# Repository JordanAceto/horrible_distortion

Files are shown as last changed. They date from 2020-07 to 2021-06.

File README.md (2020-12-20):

## stm32 based bitcrusher pedal

bit crusher pedal 

## Repository organization
- Schematics, BOM, kicad files, and gerbers are in the [hardware](https://github.com/JordanAceto/bit_crusher_pedal/tree/master/hardware) directory.
- Source files and instructions on how to flash the firmware are in the [firmware](https://github.com/JordanAceto/bit_crusher_pedal/tree/master/firmware) directory.
- The [reference_docs](https://github.com/JordanAceto/bit_crusher_pedal/tree/master/reference_docs) directory contains various datasheets for the components used by the system.
- There is a [user manual](https://github.com/JordanAceto/bit_crusher_pedal/tree/master/user_manual.pdf) in the root directory.

---

## License:
-  hardware: CC by 4.0
-  software: MIT license
-  by: Jordan Aceto

---

## Status of the project:

revision | schematic | pcb layout | firmware | built and tested |
---------|-----------|------------|----------|------------------|
1.1      | &#9745;   | &#9745;    | &#9745;  | &#9745;          |

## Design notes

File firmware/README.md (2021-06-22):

# STM32F334K6 bitcrusher firmware

## Brief overview of the algorithm:

ADC1 reads the control signals for bit-depth and sample rate automatically at a sample rate set by timer 3.
The control parameters are saved in a global signal via the DMA controller.

The audio signal is read by ADC2, triggered by timer 6, at a variable sample rate set by the sample-rate control signal.

The digitized audio signal is then processed by the bit crusher algorithm and output via DAC1.

A simple bicolor LED indicator is attached to two GPIO pins and acts as a basic signal strength and clipping indicator.

---

## Prerequisites for building and flashing the project:
- [arm-none-eabi toolchain](https://developer.arm.com/tools-and-software/open-source-software/developer-tools/gnu-toolchain/gnu-rm/downloads)
- [GNU make](https://www.gnu.org/software/make/)
- [st-link utility](https://www.st.com/en/development-tools/stsw-link004.html)
- A physical st-link device. I use an old [Nucleo board](https://www.st.com/en/evaluation-tools/stm32-nucleo-boards.html).
- If you have a different preferred method of flashing STM32 chips (openocd, etc) then feel free to go wild.

### To build the project:
- `$ make`

### To flash an STM32f334 chip connected to an st-link programmer via the SWD header:
- `$ make write`

---

## Firmware directory organization:
- `third_party` contains the STM32 supplied CMSIS files, assembly startup routine, and linker script.
- `BSP` is a very basic "Board Support Package", this module initializes and modifies the various stm32 peripherals used by the system.
- `lib` contains user library files.
- `src` contains the main application files.
- `bin` is the destination for output files generated by the build process.

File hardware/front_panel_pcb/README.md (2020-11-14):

# front panel:

## The front panel is simply a cheap and cheerful pcb panel, as an alternative to dymo labels or silkscreening 

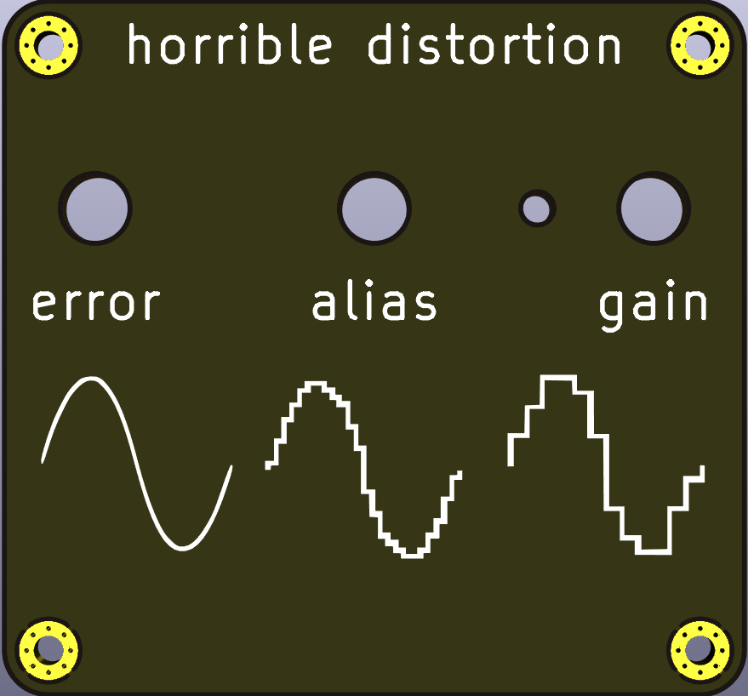
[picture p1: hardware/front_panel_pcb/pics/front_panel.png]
front panel


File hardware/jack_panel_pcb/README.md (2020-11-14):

# jack panel:

## The jack panel is simply a cheap and cheerful pcb panel, as an alternative to dymo labels or silkscreening 

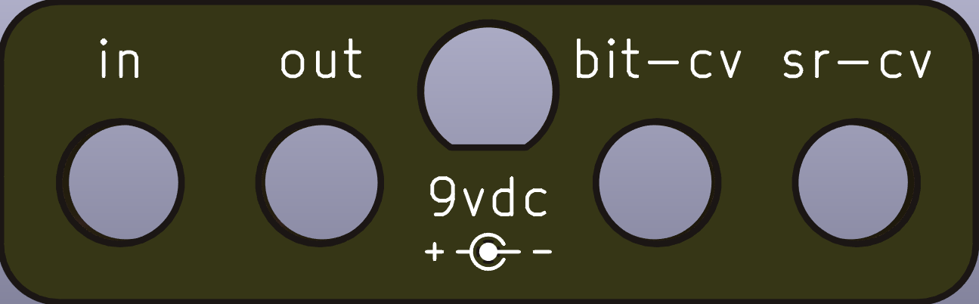
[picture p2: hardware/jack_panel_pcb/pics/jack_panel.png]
jack panel


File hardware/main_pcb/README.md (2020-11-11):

# main pcb:

<br /><br />

## The main pcb contains all the circuitry for the effect, excluding the 1/4" jacks, 9vdc power entry jack, and true-bypass footswitch. These off-board components are connected to the main pcb with soldered flying wires. 

<br /><br />

---

## Description of the audio circuit:

The audio signal is immediately buffered by a FET source-follower which provides a high impedance input as expected by guitars and other musical instruments.

The signal is then compressed by 1/2 of an NE570 compandor chip configured as a compressor. This compression squishes the audio signal into a reduced range so that both quiet and loud signals take up enough ADC resolution for the algorithm to work with.

The compressed audio signal is then sent to a variable gain amplifier where the user can adjust the magnitude of the signal entering the ADC to taste. This amplifier also acts as a clipping amplifier to protect the ADC from signals outside of its voltage range. A bi-color LED acts as a signal strength and clipping indicator as an aid to the user in setting a healthy signal level.

Now the signal is read in to the microcontroller by an onboard ADC and processed internally.

The processed digitized signal is then converted back to an analog signal by the microcontrollers onboard DAC.

The output of the DAC is fed into an opamp low pass filter to attenuate very high frequencies outside of the audio band.

The filtered processed signal is finally sent to the other half of the NE570 configured as an expandor this time. This restores the dynamic range of the original audio signal.

<br /><br />

---

## Description of the control circuit:

Control voltage signals for bit-depth and sample-rate are generated by opamps. The contribution of onboard rotary potentiometers and optional external control voltage signals are summed and inverted.

The opamp control voltage generators also act as protection for the ADC. Control voltages outside of the safe range for the ADC will be harmlessly clipped by the opamps.

These control voltage signals are then read in to the microcontroller by onboard ADCs and used to process the audio signals.

The external CV input ports can accept either voltage signals in the range of 0 volts to +5 volts, or they can accept an expression pedal connected to a TRS jack.

Because different brands of expression pedals use different potentiometer values, trim-pots are included to calibrate the device for various expression pedals.

<br /><br />

---

## Errata:

A port for an optional on/off LED indicator is included on the main pcb. If desired attach a panel mounted LED to this port through a spare pole of a bypass switch.

An SWD header is used to program and debug the STM32 microcontroller.

This project is intended as a "guitar pedal" type effects box which fits in a Hammond 'BB' style enclosure. The main pcb is affixed to the enclosure with the pcb mounted potentiometers. Flying wires are then routed to the chassis mounted 1/4" jacks, 9vdc power input jack, and true-bypass footswitch.

There are optional mounting holes if a different mechanical setup is desired.

<br /><br />

---

## Top and bottom render of the main pcb:

<br /><br />
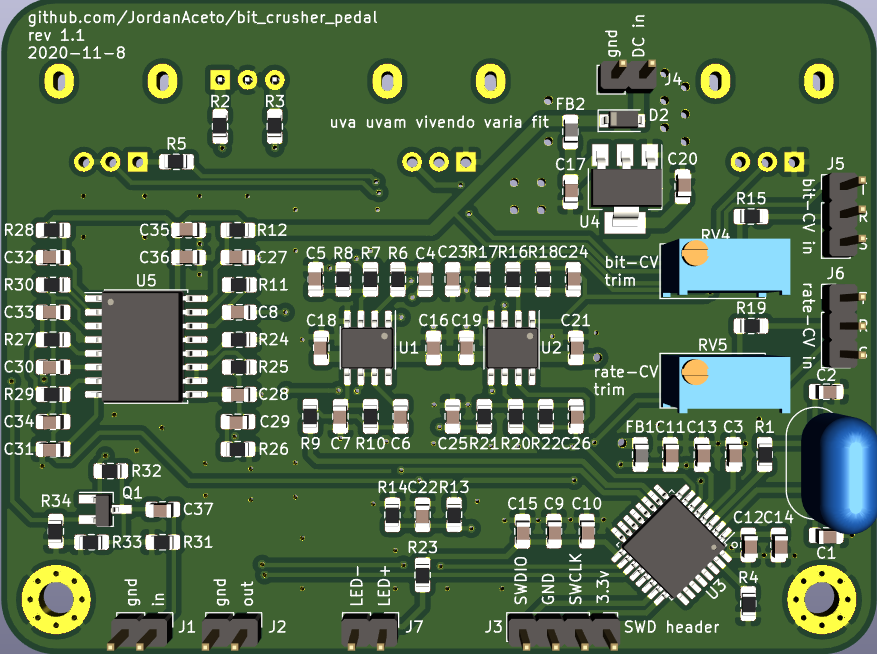
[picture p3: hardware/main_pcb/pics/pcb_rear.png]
main pcb


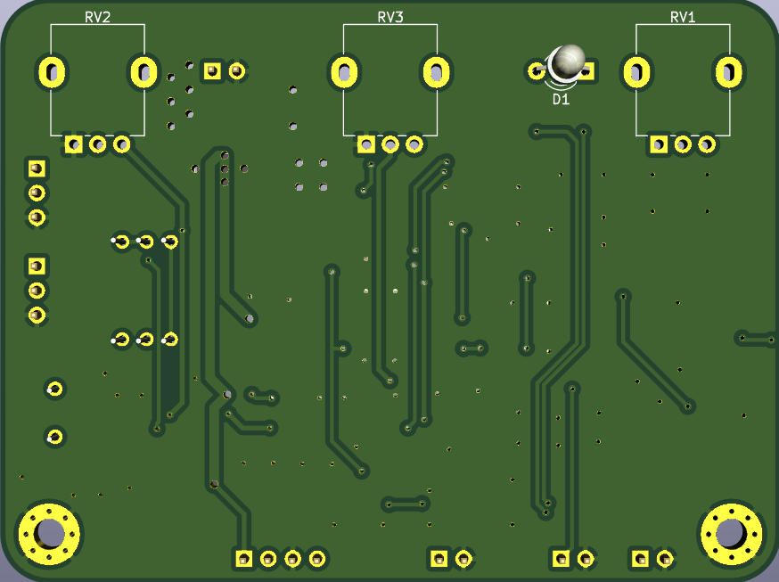
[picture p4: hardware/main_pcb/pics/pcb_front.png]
main pcb


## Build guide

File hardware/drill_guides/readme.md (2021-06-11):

## Printable drill guides





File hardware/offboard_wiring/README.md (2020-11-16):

# Offboard wiring

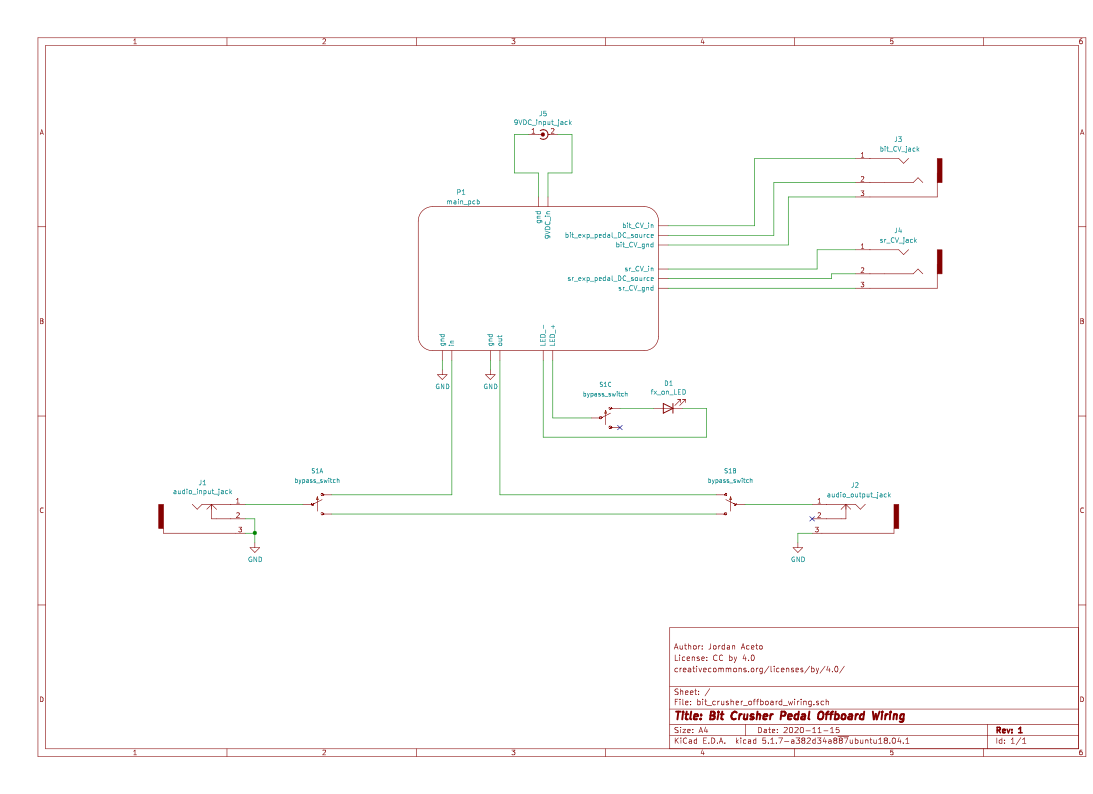
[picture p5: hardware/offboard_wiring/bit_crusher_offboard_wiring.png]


This directory simply contains a wiring diagram for the offboard components that
are wired to the main pcb with flying wires.

These components are:
- signal input and signal output jacks
- 9vdc power input jack
- bypass switch
- fx on/off indicator LED
- bit-depth and sample-rate CV input/expression pedal jacks

The builder is free to chose jacks, switches, and LEDs that work well for their
chosen enclosure.

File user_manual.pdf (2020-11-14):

# horrible distortion

- bit-crusher/sample-rate-reducer effects pedal -

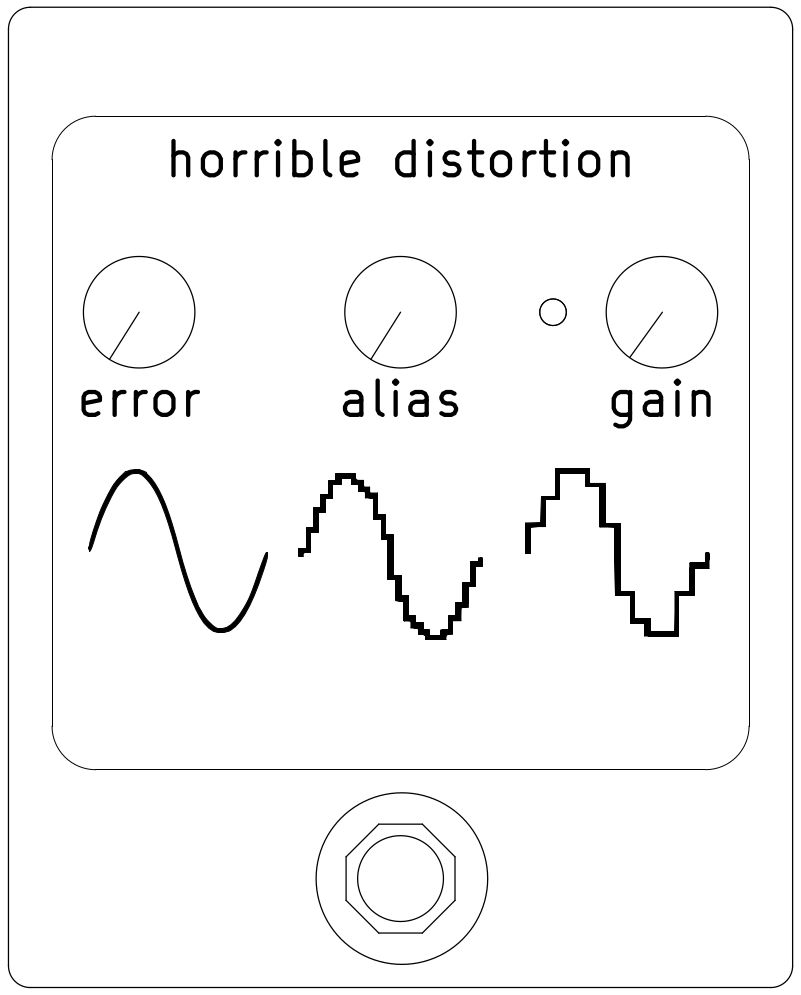
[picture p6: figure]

More docs and open source files at: github.com/JordanAceto/bit_crusher_pedal

Page | 1 | bit-crusher user manual

### Overview:

The horrible distortion pedal creates digital distortion and aliasing effects. Variable bit-depth and sample-rate parameters cause quantization noise, distortion, and harsh alias frequencies. How gauche.

### Front panel controls

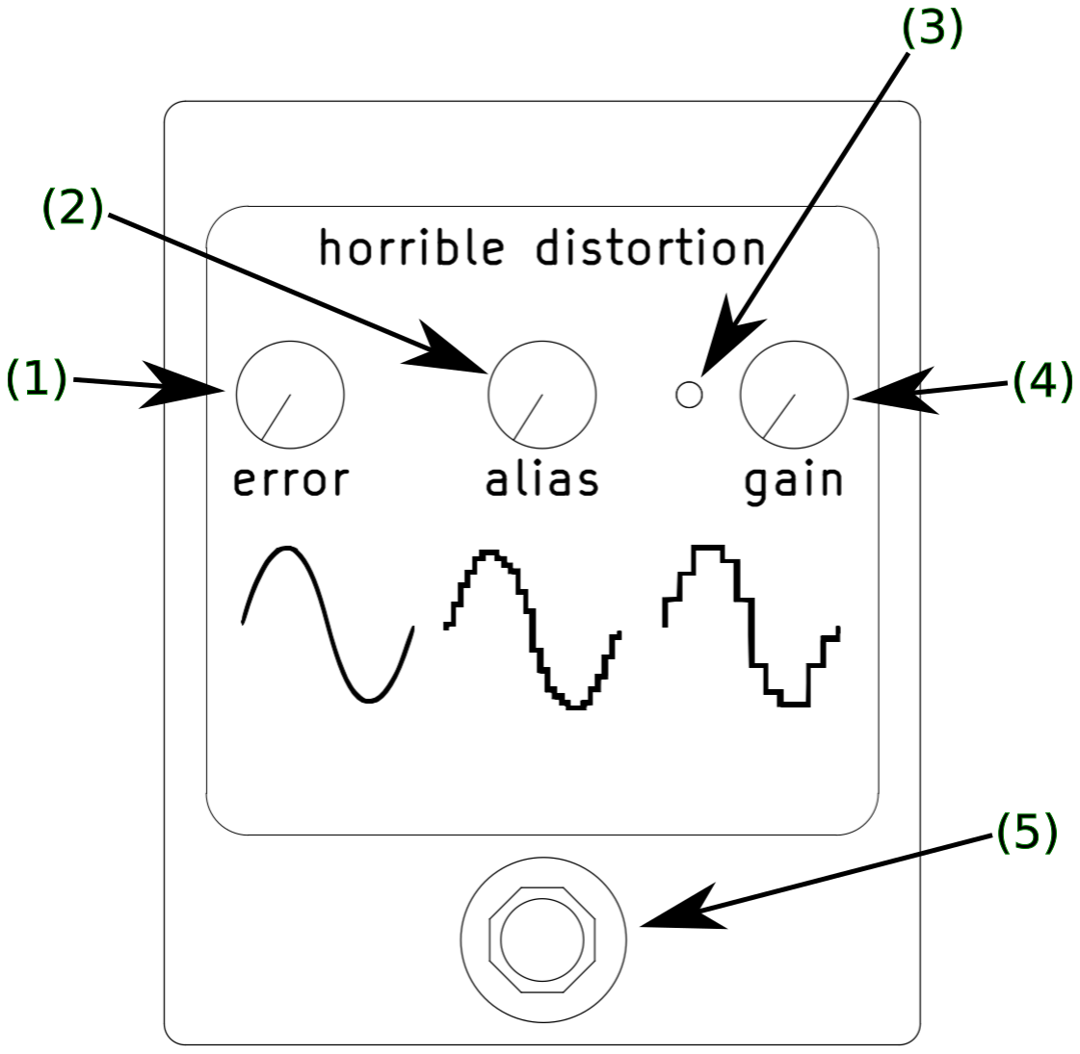
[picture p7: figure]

1) Error control which sets the bit-depth. As the control is advanced clockwise, the bit-depth resolution is decreased and harsh noise and distortion are introduced.
2) Alias control which reduces the sample-rate. Advancing this control clockwise adds alias frequencies and causes the frequency of the input signal to become unintelligible.
3) The signal level indicator gives a visual indication of the signal strength. The LED will be green when the signal level is in the healthy range, orange when approaching clipping, and red when clipping.
4) Gain control which sets the signal level. Adjust this control so that the LED is green most of the time while playing and the output volume is at the desired level.
5) True-bypass stomp switch which turns the effect on and off.

Page | 2 | bit-crusher user manual

### IO Jacks

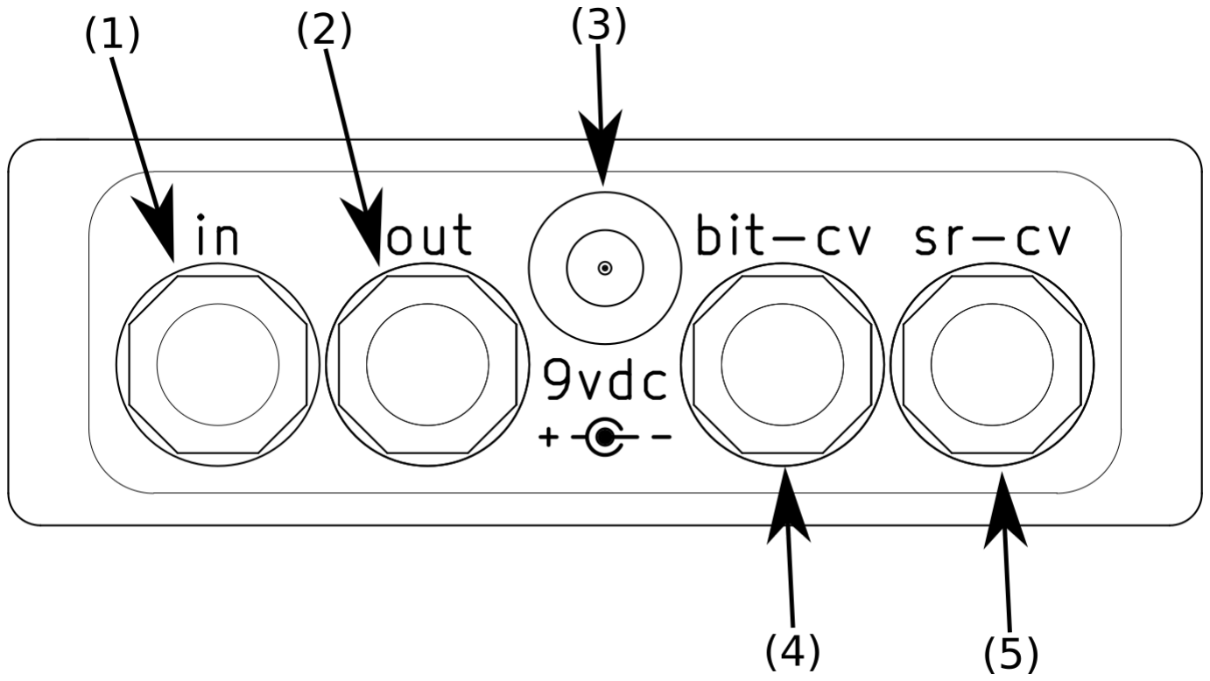
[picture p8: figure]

1) Audio signal input. Connect a guitar/synth/voice/drums/other instrument here.
2) Audio signal output jack. Connect this to an amplifier.
3) Plug a standard guitar pedal style 9-volt DC center-negative power supply here to energize the pedal.
4) The bit-cv jack accepts control voltages or expression pedals. Control signals injected into this jack modulate the bit-depth parameter in conjunction with the error rotary control.
5) Likewise, the sr-cv jack is the control voltage input for the sample-rate parameter. Control signals injected here modulate the sample-rate parameter in conjunction with the alias rotary control.

Page | 3 | bit-crusher user manual

### Control voltage input range

The bit-cv and sr-cv jacks expect control voltages between 0 volts and +5 volts. Control voltages outside this range will not harm the pedal, but will not modulate the parameters further.

### Expression pedal calibration

The bit-cv and sr-cv jacks can accept either control voltages or expression pedals. Expression pedals come in a variety of potentiometer values, and the pedal can be calibrated for the specific expression pedal you chose to use. You will need a multi meter and some basic electronics skills to carry out the calibration.

To calibrate the bit-cv expression pedal input:

- Connect the expression pedal you intend to use to the bit-cv jack.
- Remove the back cover with a screwdriver.
- Monitor across the outer terminals of the expression pedal potentiometer with a multimeter set to measure DC volts.
- Adjust the trimpot on the main circuit board labeled “bit-CV trim” until you read +5 volts across the expression pedal potentiometer.

Calibration of the sr-cv input is identical. Plug the expression pedal into the sr-cv jack and adjust the “rate-CV trim” trimpot.

If you do not have access to a multi meter, then the expression pedals can be calibrated by ear as well. Simply plug in an expression pedal and rock it through its range with various settings of the front panel controls and adjust the trim pots until the range of the expression pedal feels good.

The goal of the calibration is to make the sweep of the expression pedal feel right for your playing style and setup, so if it sounds good, it is good.

### Current Consumption

The pedal consumes approximately 50 mA from the 9 vdc power supply.

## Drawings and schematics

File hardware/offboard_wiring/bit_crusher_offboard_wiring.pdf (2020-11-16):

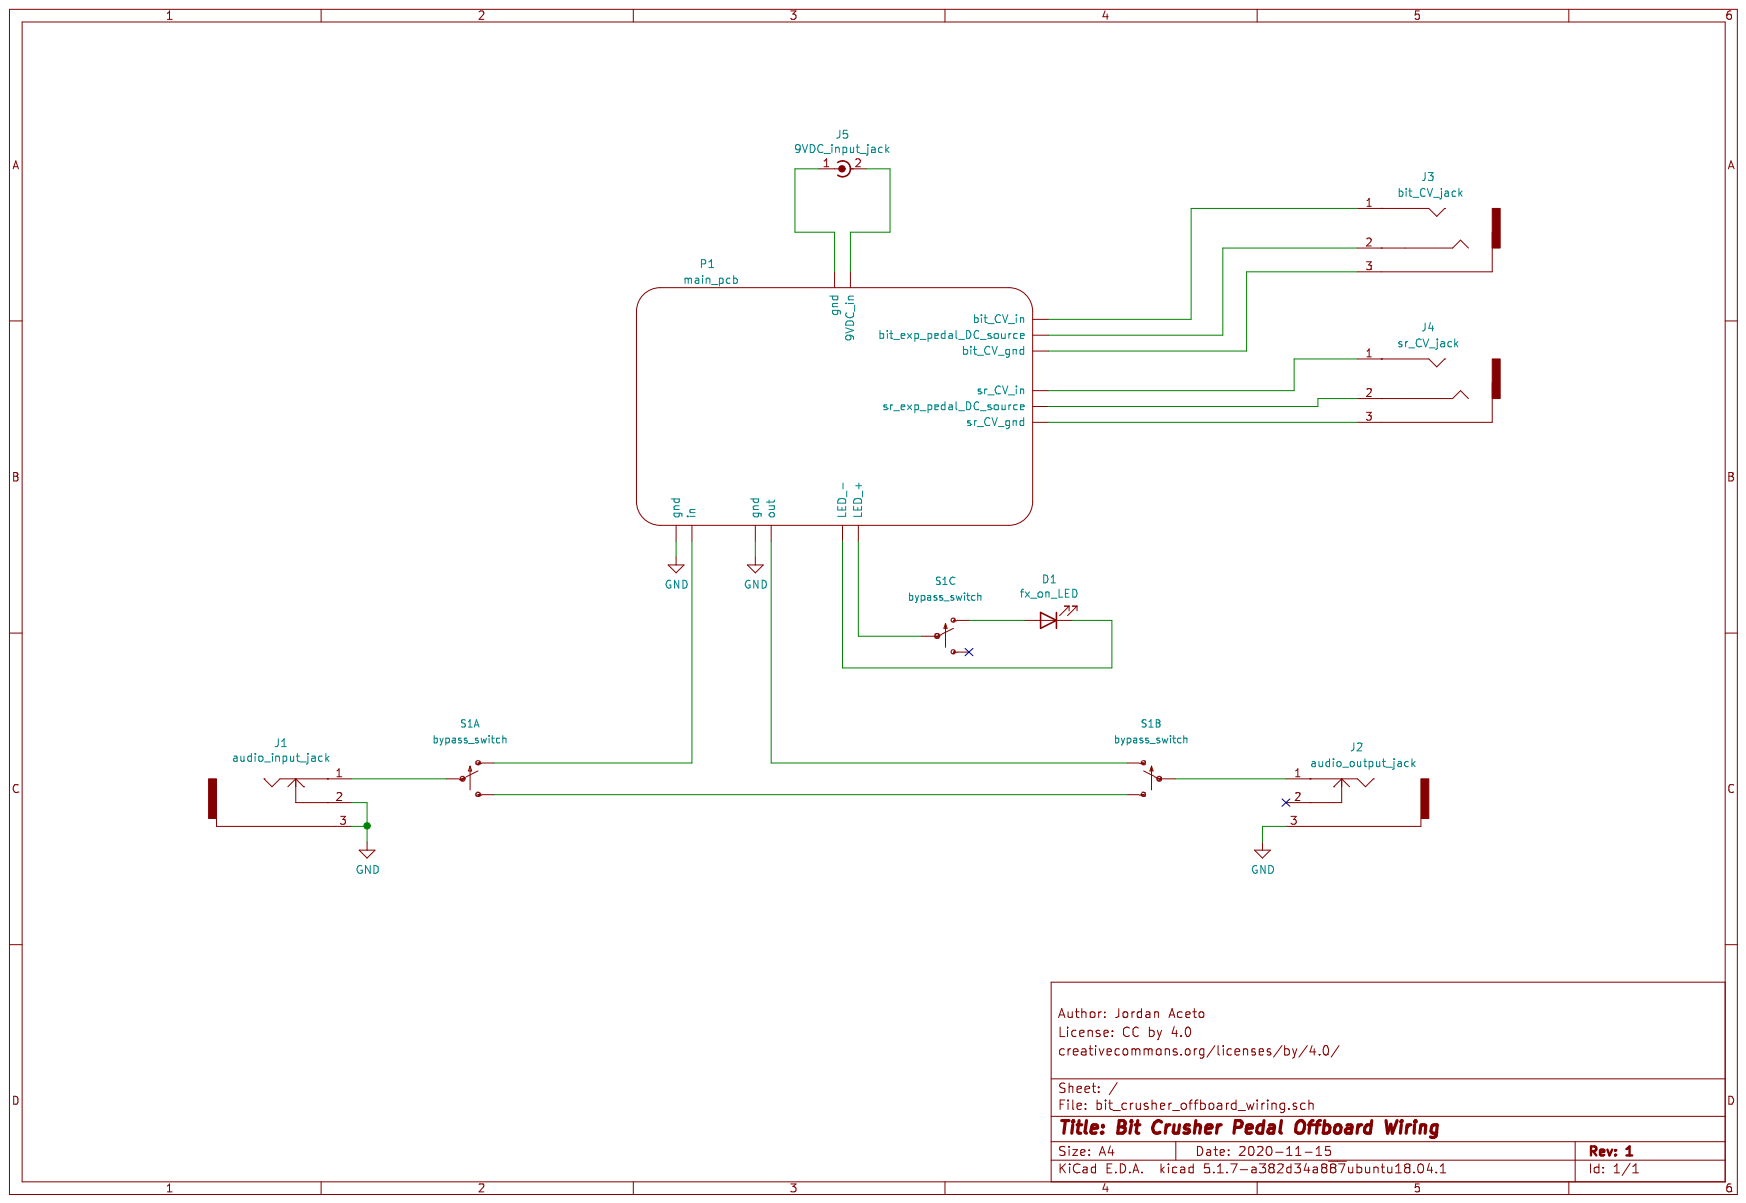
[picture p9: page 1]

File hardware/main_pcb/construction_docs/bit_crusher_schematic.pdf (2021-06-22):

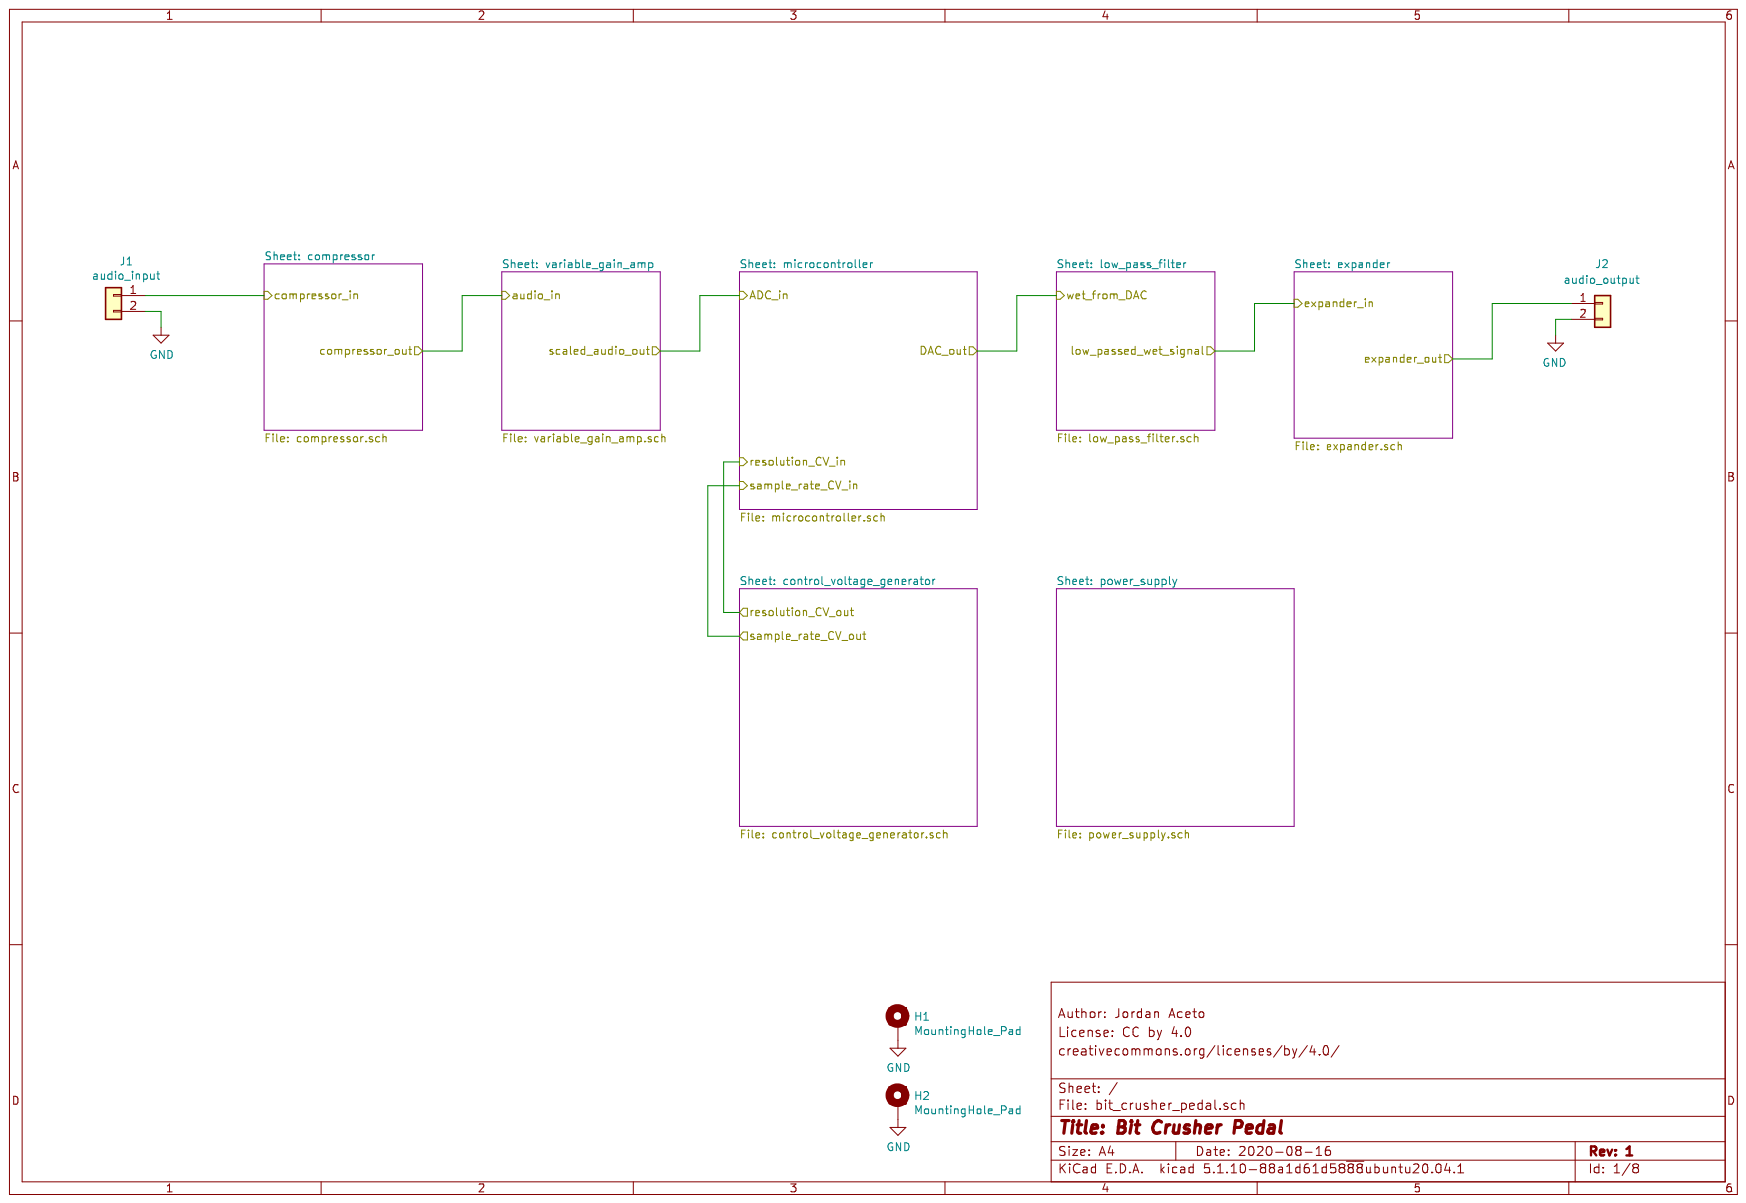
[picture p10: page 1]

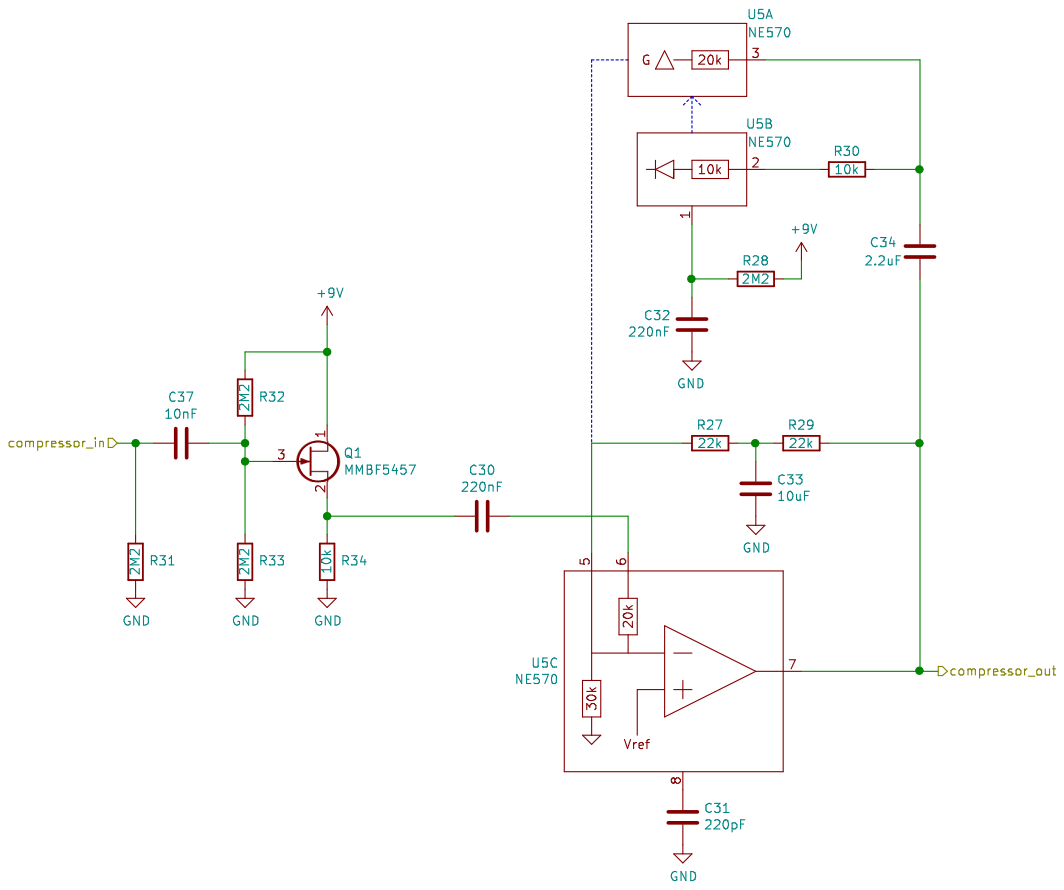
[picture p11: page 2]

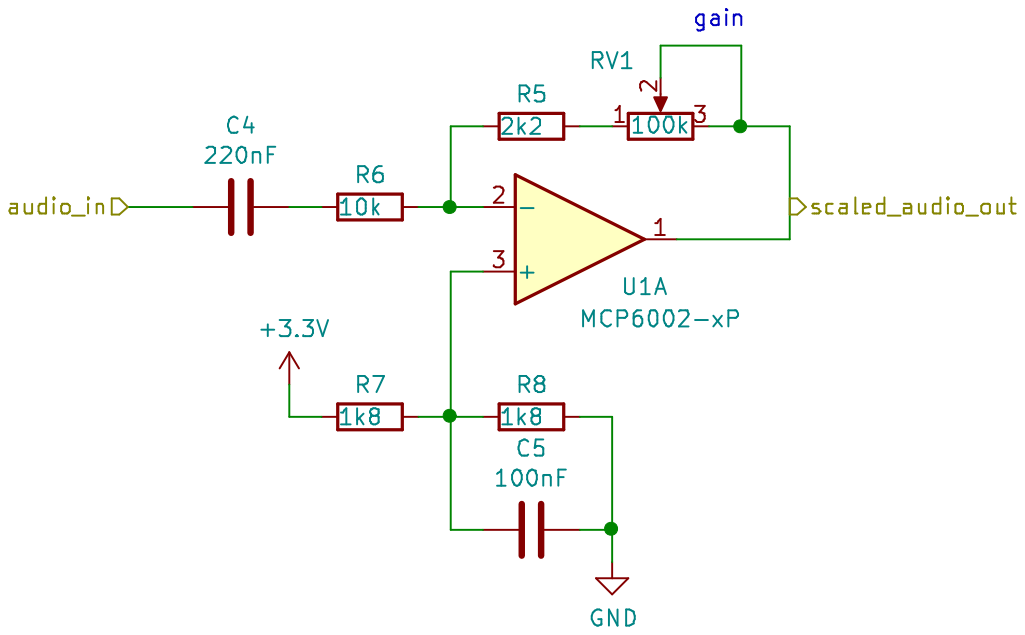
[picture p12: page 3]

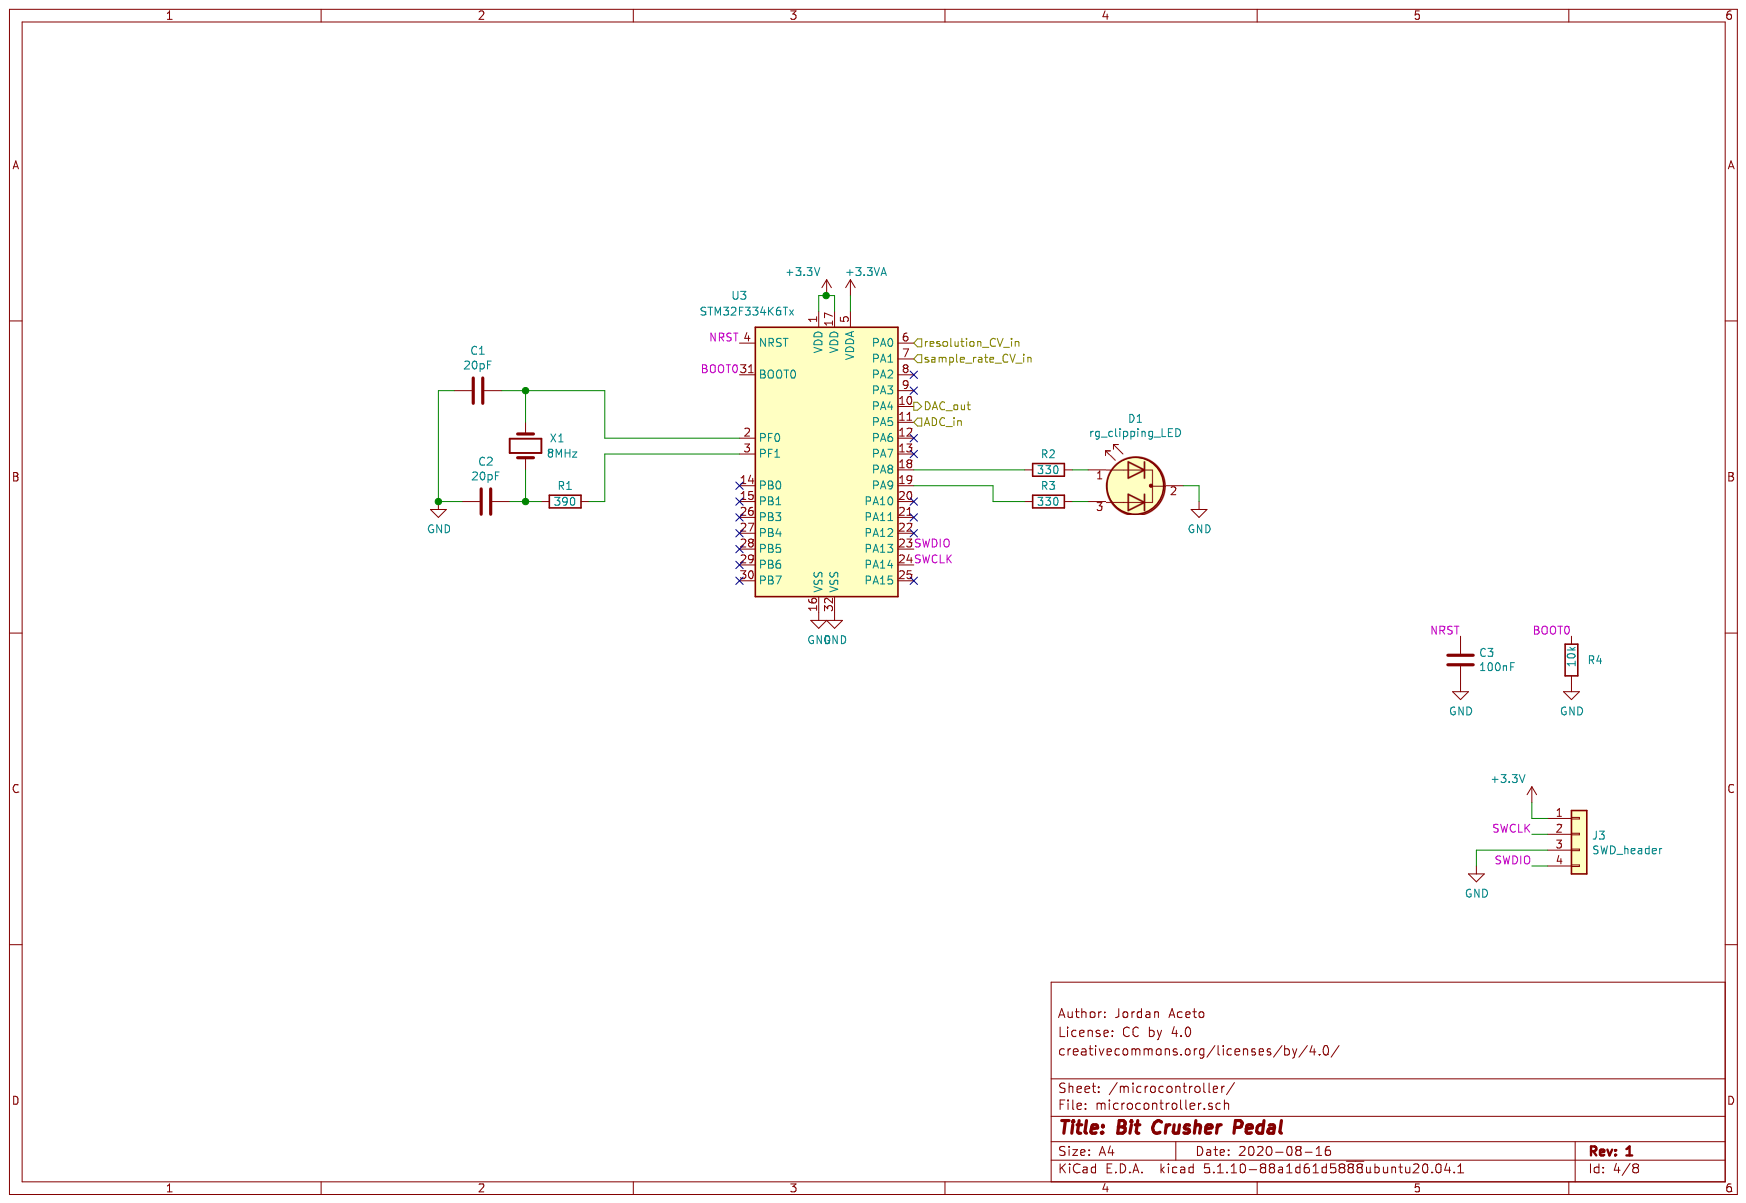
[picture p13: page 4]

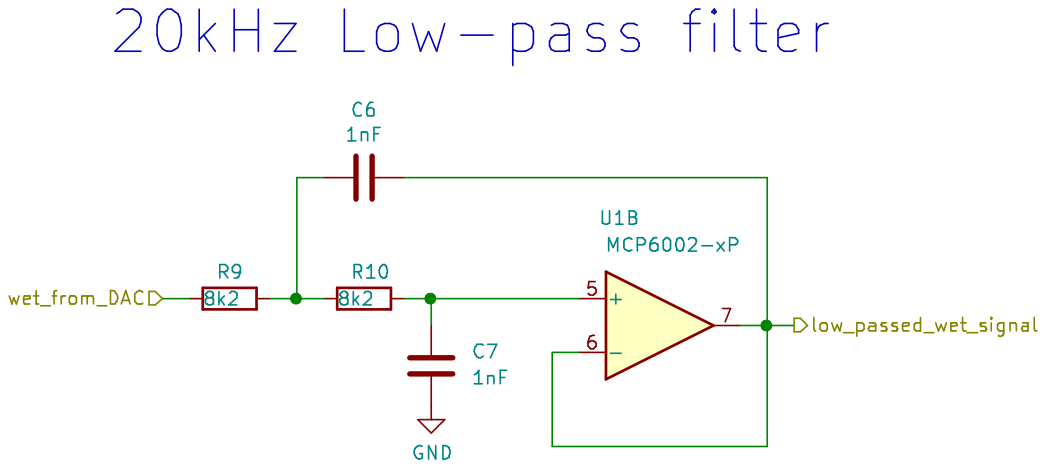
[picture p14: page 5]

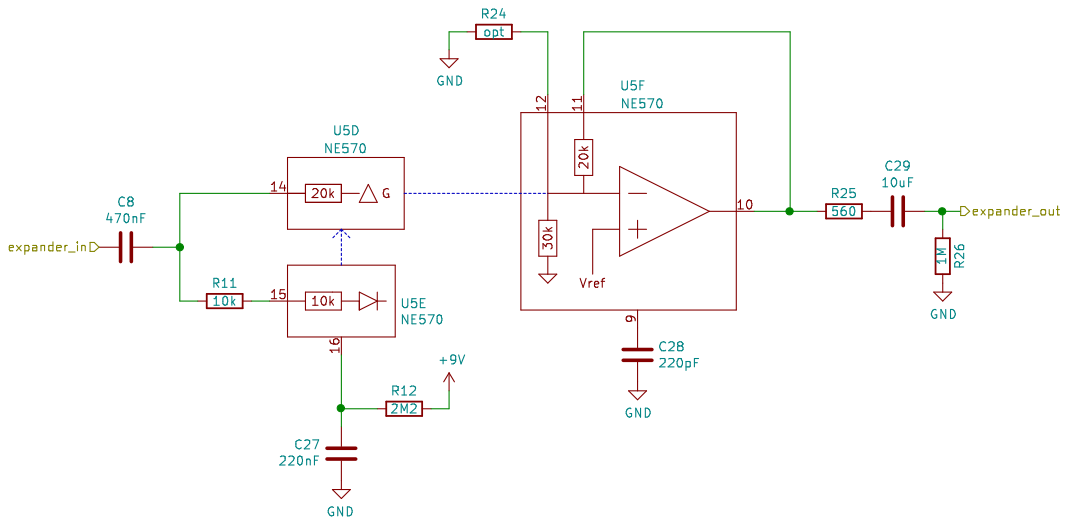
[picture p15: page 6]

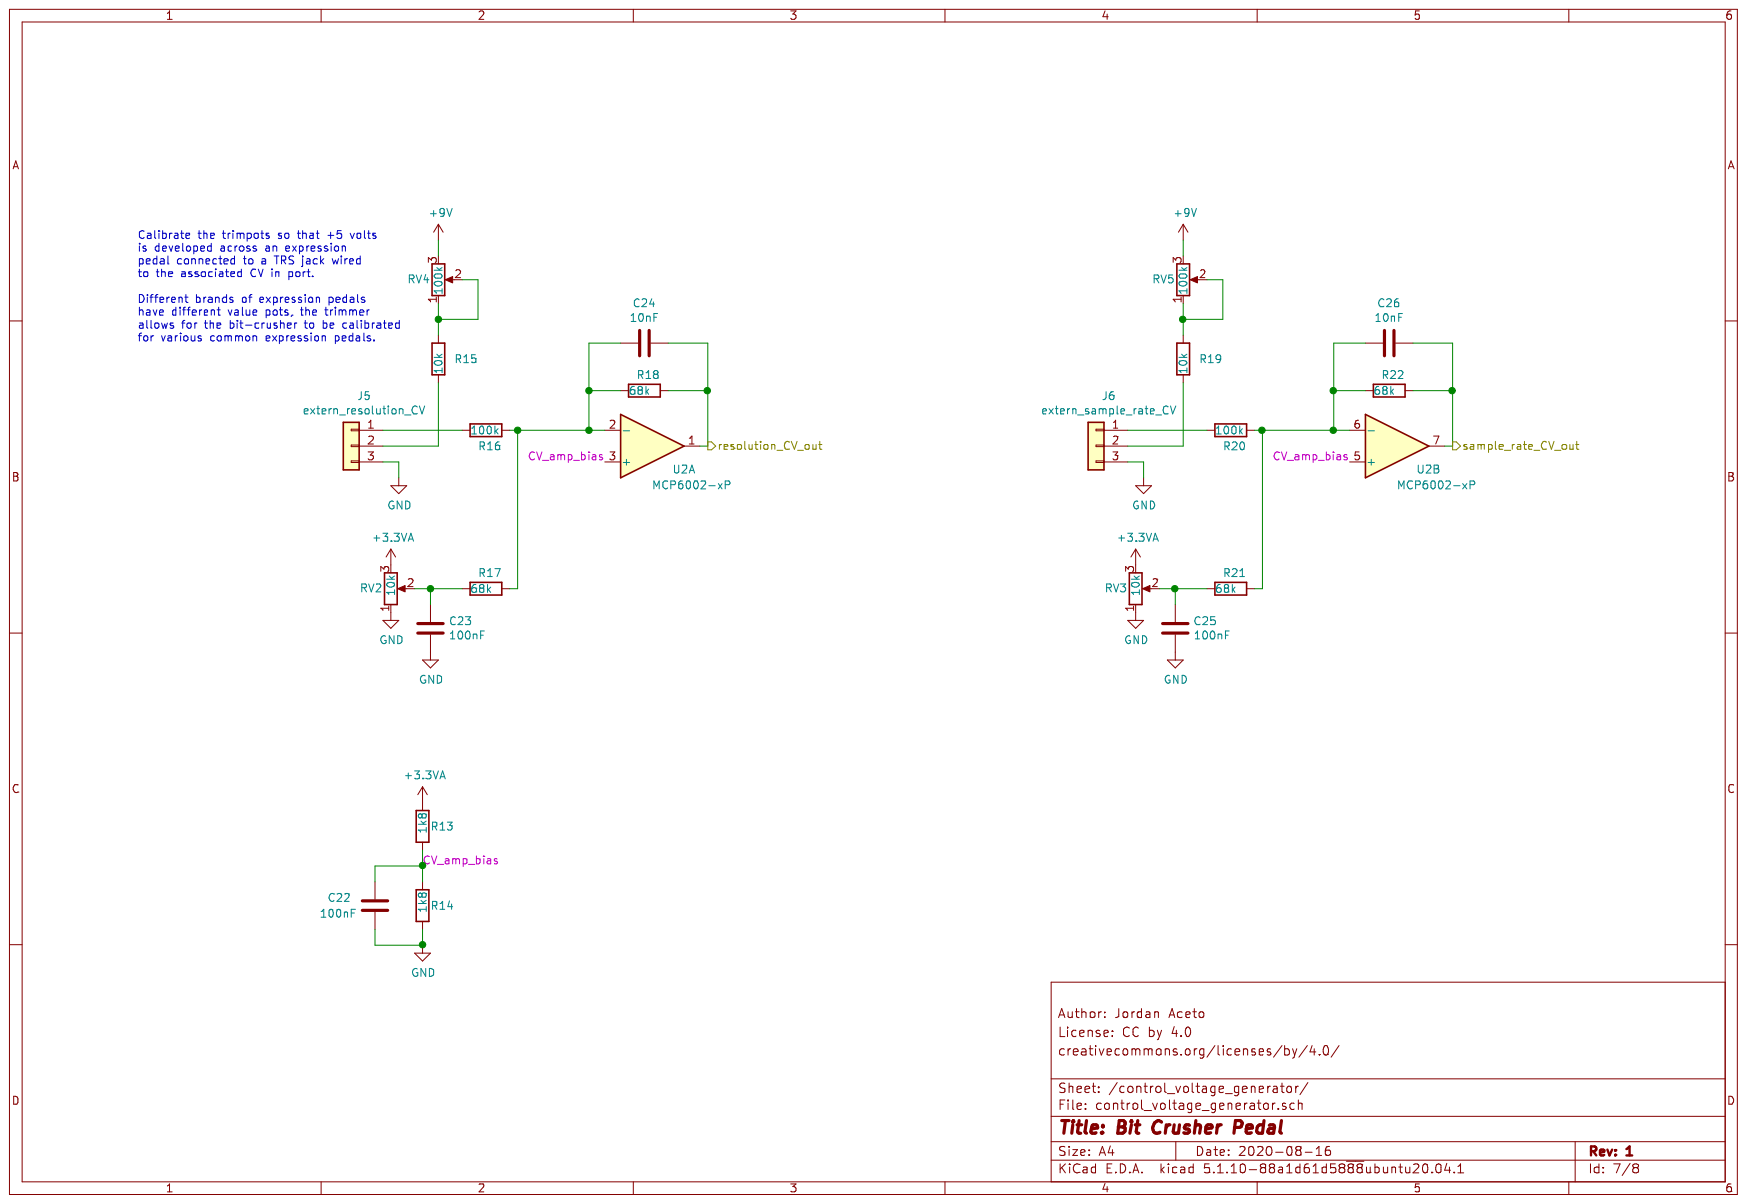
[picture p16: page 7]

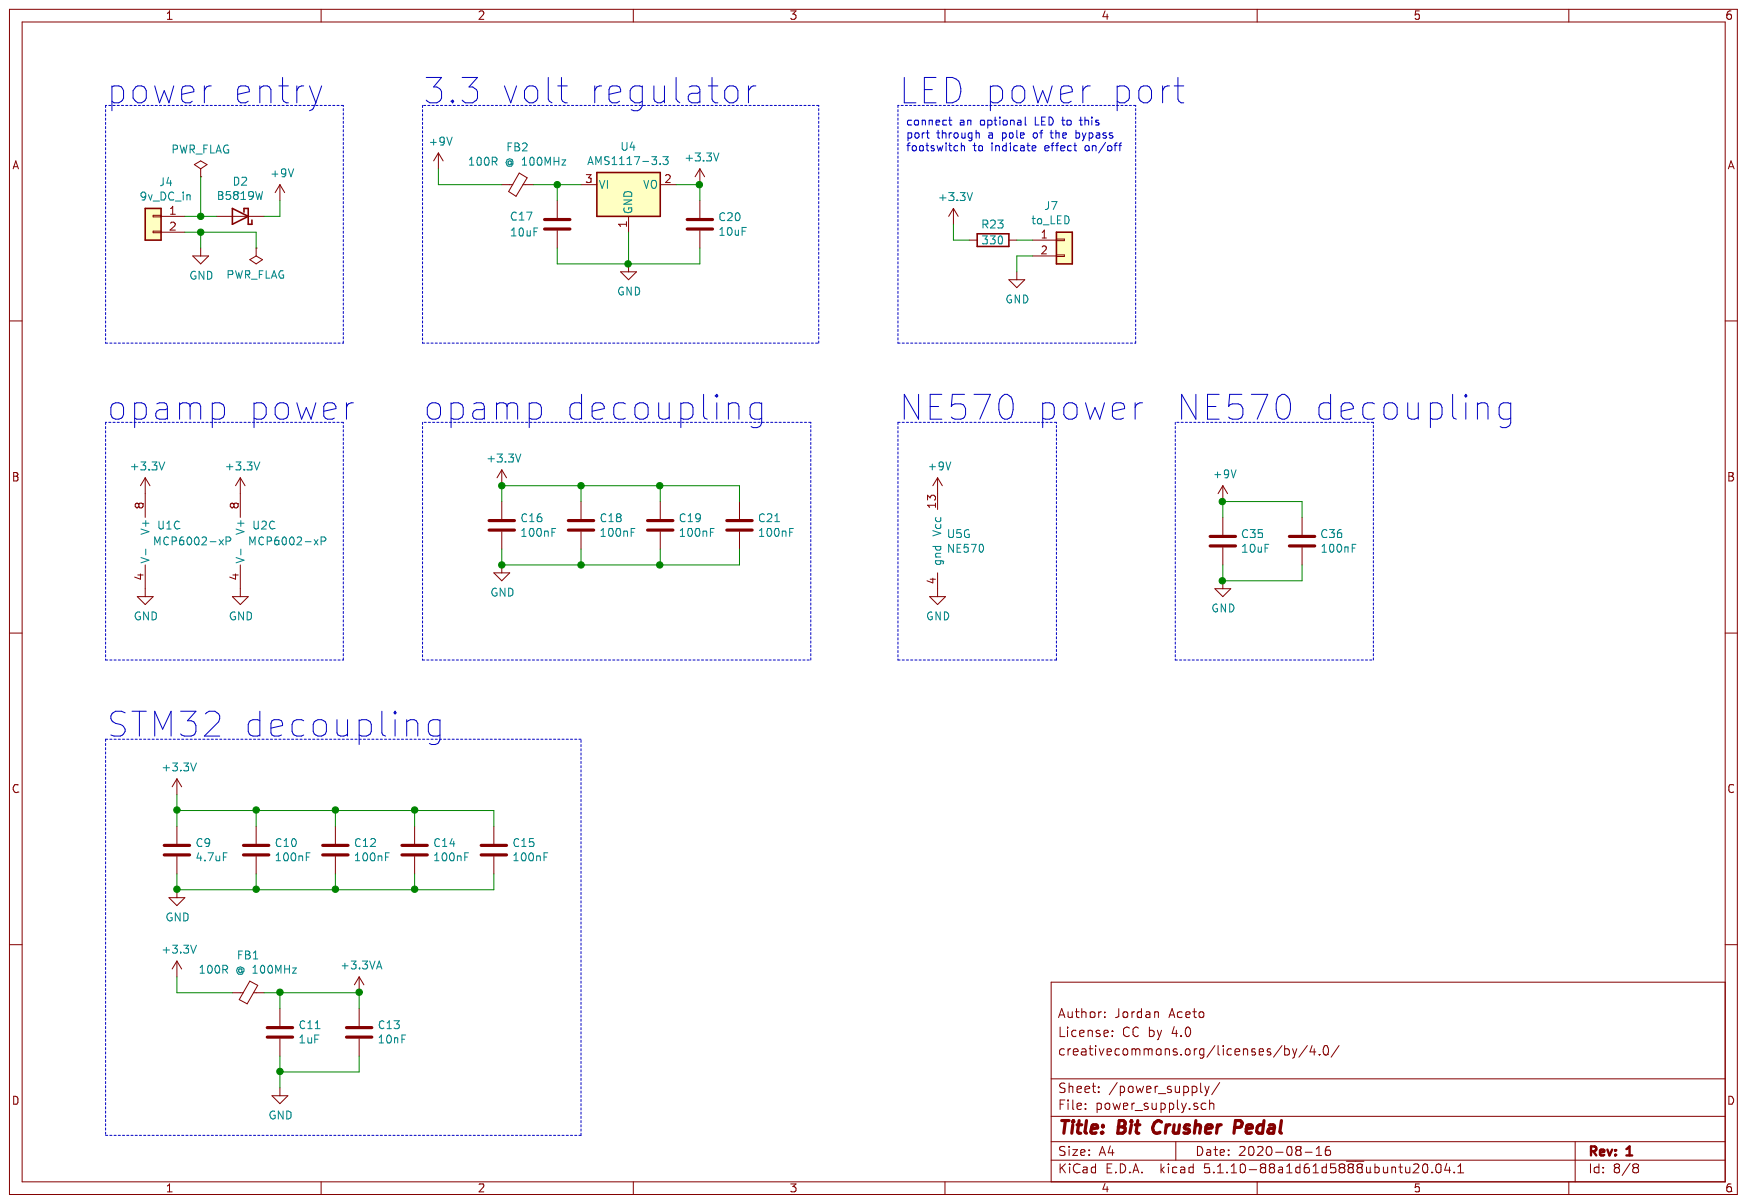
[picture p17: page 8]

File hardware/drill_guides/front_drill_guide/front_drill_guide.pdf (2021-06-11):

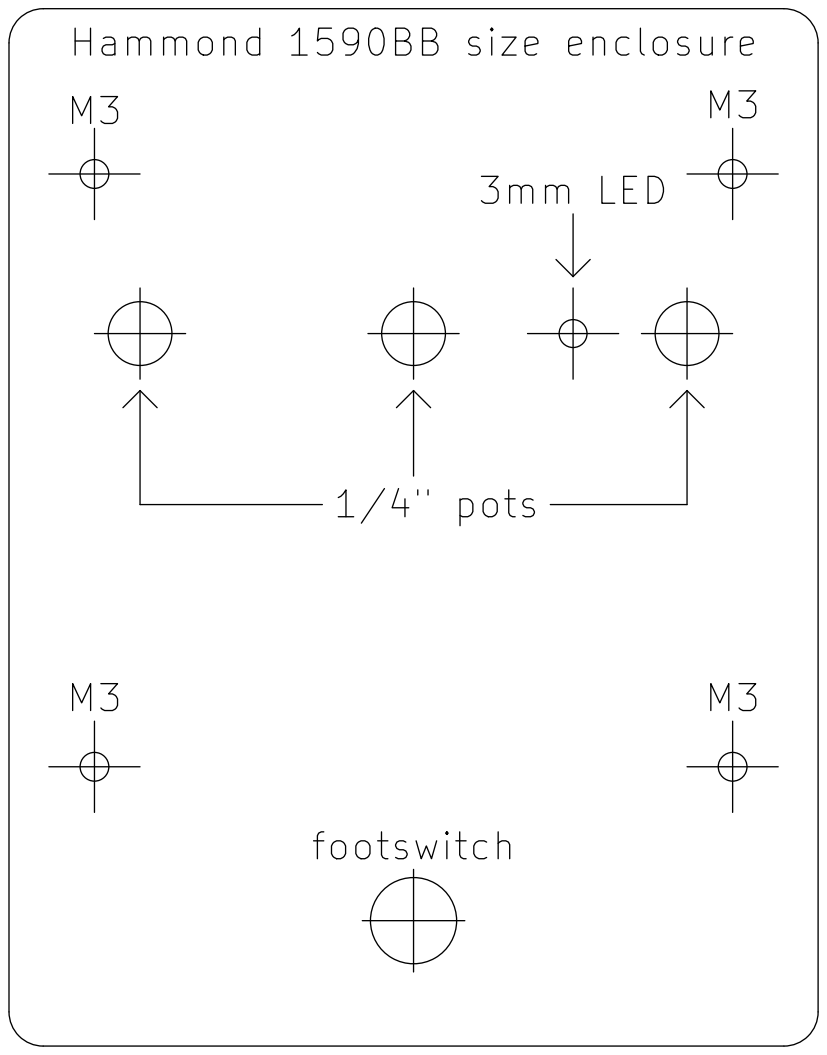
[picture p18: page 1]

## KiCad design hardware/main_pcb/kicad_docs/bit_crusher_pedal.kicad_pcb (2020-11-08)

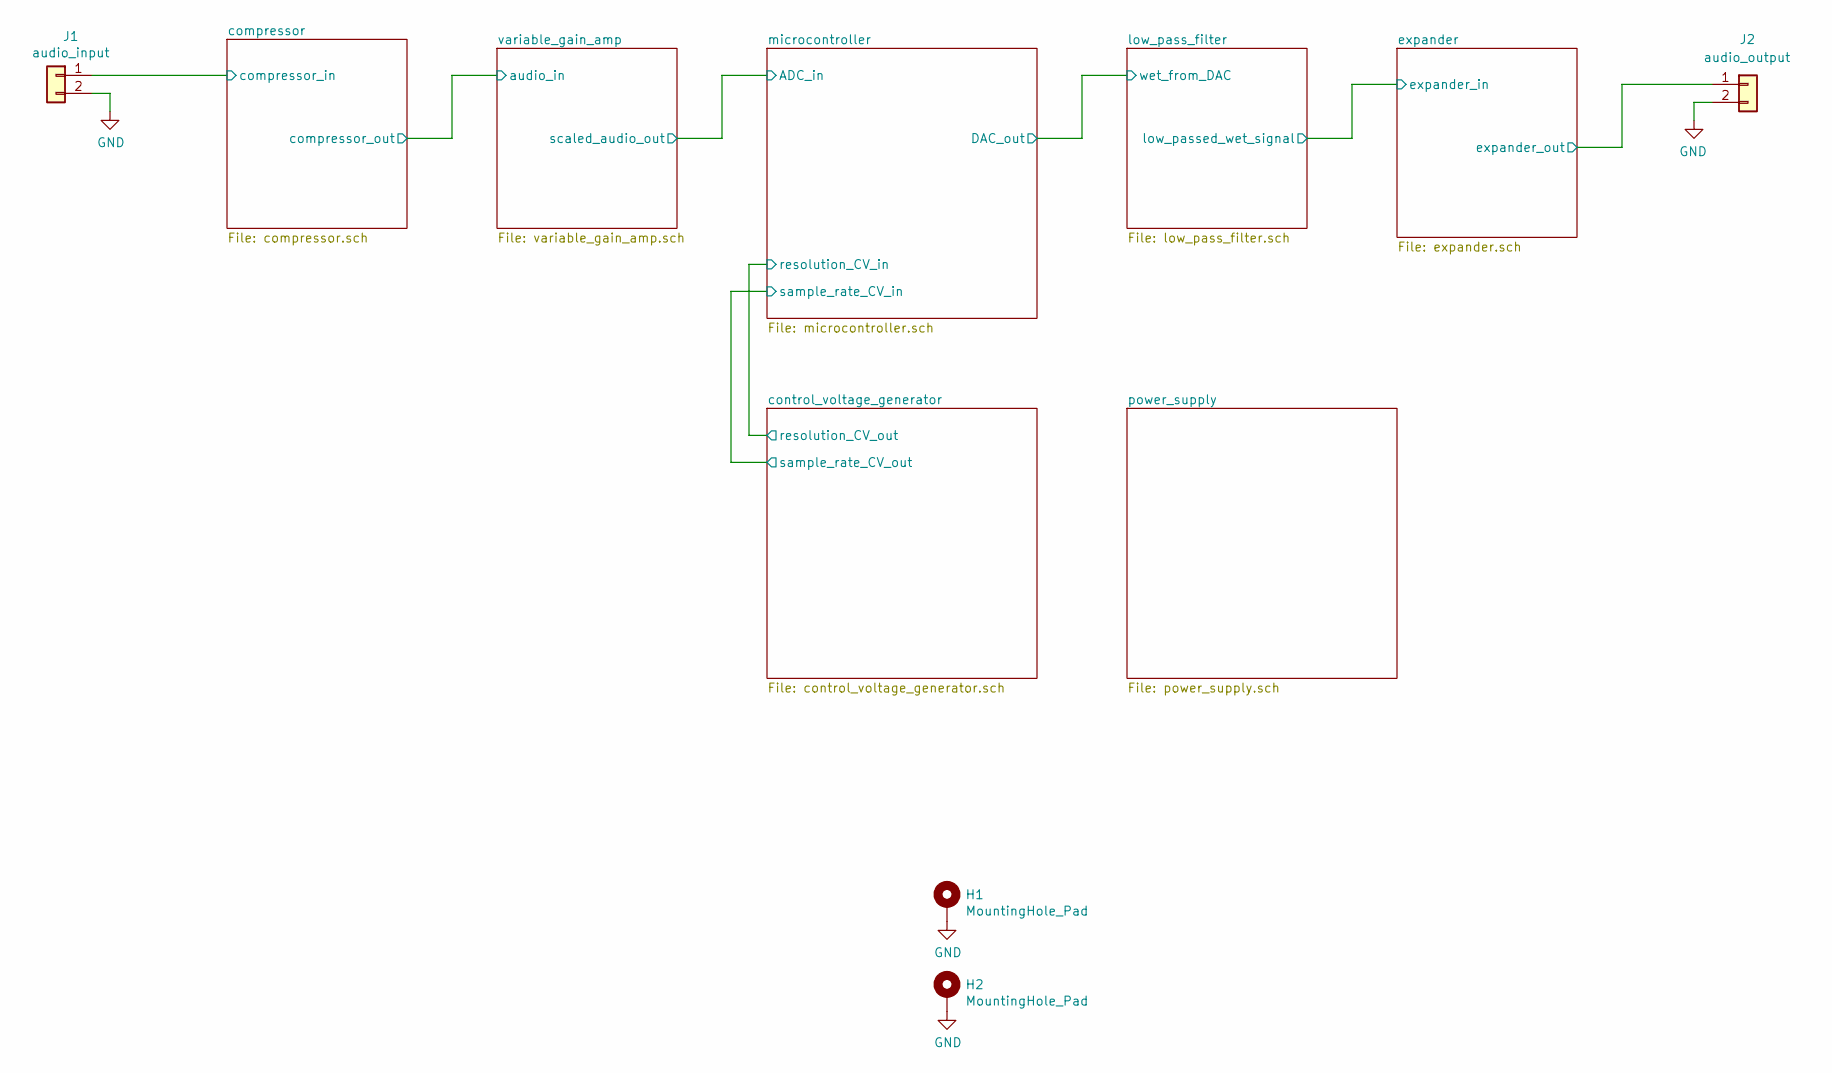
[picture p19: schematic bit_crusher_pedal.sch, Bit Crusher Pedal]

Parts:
H1, H2: MountingHole_Pad; MountingHole_3.2mm_M3_Pad_Via
J1: audio_input; PinHeader_1x02_P2.54mm_Vertical
J2: audio_output; PinHeader_1x02_P2.54mm_Vertical

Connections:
/compressor/compressor_in: J1.1; also elsewhere on the board
/expander/expander_out: J2.1; also elsewhere on the board
GND: H1.1, H2.1, J1.2, J2.2; also elsewhere on the board

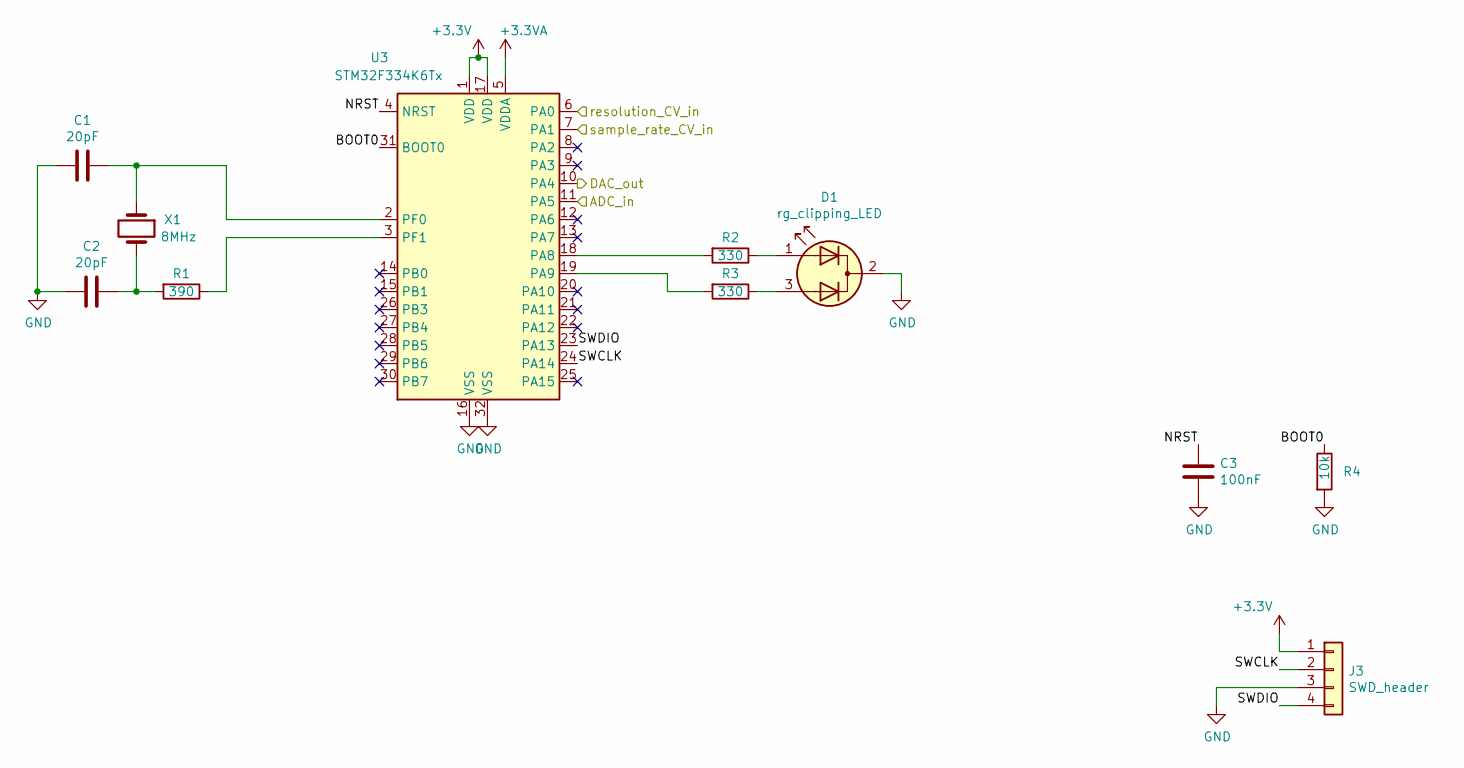
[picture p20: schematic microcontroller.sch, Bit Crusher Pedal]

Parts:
C1, C2: 20pF; C_0805_2012Metric_Pad1.15x1.40mm_HandSolder
C3: 100nF; C_0805_2012Metric_Pad1.15x1.40mm_HandSolder
D1: rg_clipping_LED; LED_D3.0mm-3
J3: SWD_header; PinHeader_1x04_P2.54mm_Vertical
R1: 390; R_0805_2012Metric_Pad1.15x1.40mm_HandSolder
R2, R3: 330; R_0805_2012Metric_Pad1.15x1.40mm_HandSolder
R4: 10k; R_0805_2012Metric_Pad1.15x1.40mm_HandSolder
U3: STM32F334K6Tx; LQFP-32_7x7mm_P0.8mm
X1: 8MHz; Resonator-2Pin_W10.0mm_H5.0mm

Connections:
+3.3VA: U3.5 (VDDA); also elsewhere on the board
+3V3: J3.1, U3.1 (VDD), U3.17 (VDD); also elsewhere on the board
/microcontroller/ADC_in: U3.11 (PA5); also elsewhere on the board
/microcontroller/BOOT0: R4.1, U3.31 (BOOT0)
/microcontroller/DAC_out: U3.10 (PA4); also elsewhere on the board
/microcontroller/NRST: C3.1, U3.4 (NRST)
/microcontroller/SWCLK: J3.2, U3.24 (PA14)
/microcontroller/SWDIO: J3.4, U3.23 (PA13)
/microcontroller/resolution_CV_in: U3.6 (PA0); also elsewhere on the board
/microcontroller/sample_rate_CV_in: U3.7 (PA1); also elsewhere on the board
GND: C1.2, C2.2, C3.2, D1.2 (K), J3.3, R4.2, U3.16 (VSS), U3.32 (VSS); also elsewhere on the board
unnamed: C1.1, U3.2 (PF0), X1.1
unnamed: C2.1, R1.2, X1.2
unnamed: D1.1 (A1), R2.1
unnamed: D1.3 (A2), R3.1
unnamed: R1.1, U3.3 (PF1)
unnamed: R2.2, U3.18 (PA8)
unnamed: R3.2, U3.19 (PA9)

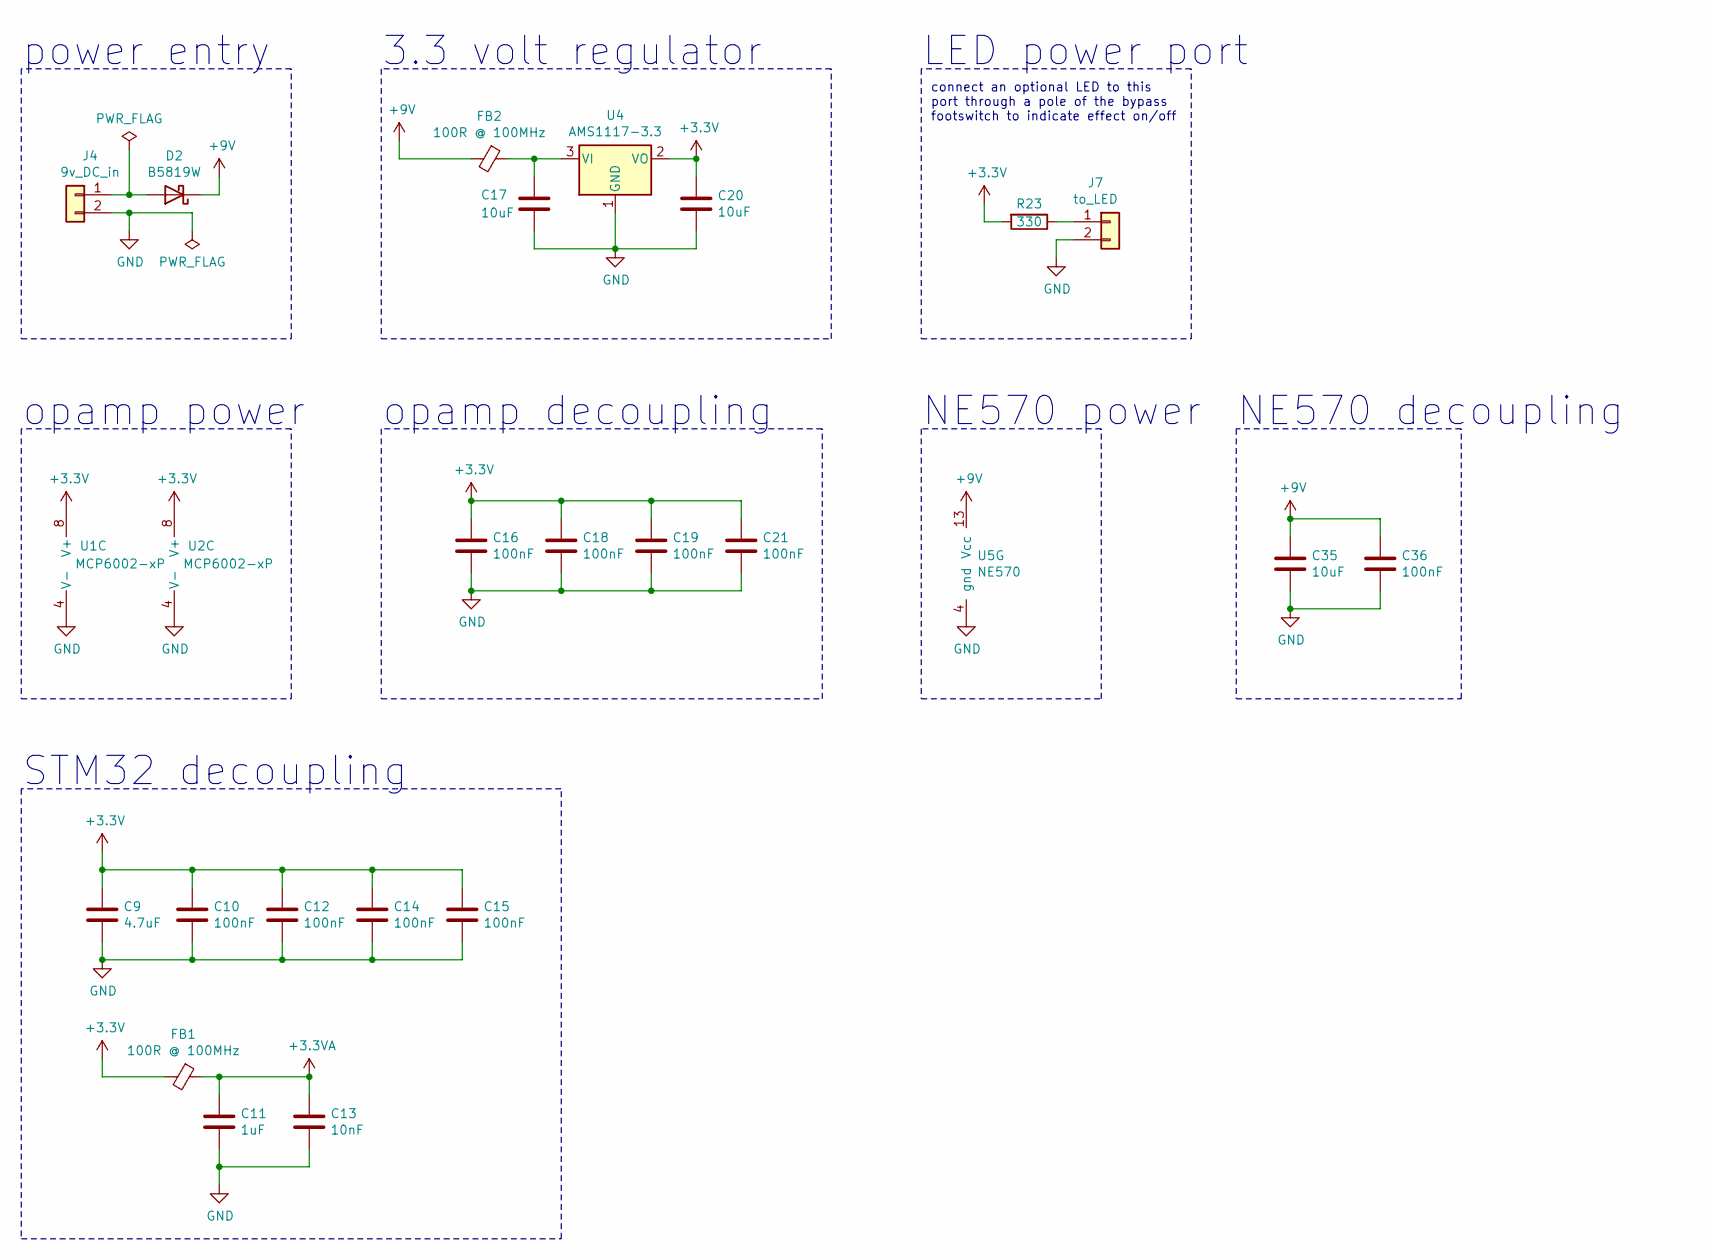
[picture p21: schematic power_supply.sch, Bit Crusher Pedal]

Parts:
C9: 4.7uF; C_0805_2012Metric_Pad1.15x1.40mm_HandSolder
C10, C12, C14, C15, C16, C18, C19, C21, C36: 100nF; C_0805_2012Metric_Pad1.15x1.40mm_HandSolder
C11: 1uF; C_0805_2012Metric_Pad1.15x1.40mm_HandSolder
C13: 10nF; C_0805_2012Metric_Pad1.15x1.40mm_HandSolder
C17, C20, C35: 10uF; C_0805_2012Metric_Pad1.15x1.40mm_HandSolder
D2: B5819W; D_SOD-123
FB1, FB2: 100R @ 100MHz; L_0805_2012Metric_Pad1.15x1.40mm_HandSolder
J4: 9v_DC_in; PinHeader_1x02_P2.54mm_Vertical
J7: to_LED; PinHeader_1x02_P2.54mm_Vertical
R23: 330; R_0805_2012Metric_Pad1.15x1.40mm_HandSolder
U1, U2: MCP6002-xP; SOIC-8_3.9x4.9mm_P1.27mm
U4: AMS1117-3.3; SOT-223-3_TabPin2
U5: NE570; SOIC-16W_7.5x10.3mm_P1.27mm

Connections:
+3.3VA: C11.1, C13.1, FB1.1; also elsewhere on the board
+3V3: C9.1, C10.1, C12.1, C14.1, C15.1, C16.1, C18.1, C19.1, C20.1, C21.1, FB1.2, R23.2, U1.8 (V+), U2.8 (V+), U4.2 (VO); also elsewhere on the board
+9V: C35.1, C36.1, D2.1 (K), FB2.2, U5.13 (Vcc); also elsewhere on the board
GND: C9.2, C10.2, C11.2, C12.2, C13.2, C14.2, C15.2, C16.2, C17.2, C18.2, C19.2, C20.2, C21.2, C35.2, C36.2, J4.2, J7.2, U1.4 (V-), U2.4 (V-), U4.1 (GND), U5.4 (gnd); also elsewhere on the board
unnamed: C17.1, FB2.1, U4.3 (VI)
unnamed: D2.2 (A), J4.1
unnamed: J7.1, R23.1

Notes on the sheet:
STM32 decoupling
3.3 volt regulator
power entry
opamp power
opamp decoupling
LED power port
connect an optional LED to this port through a pole of the bypass footswitch to indicate effect on/off
NE570 power
NE570 decoupling

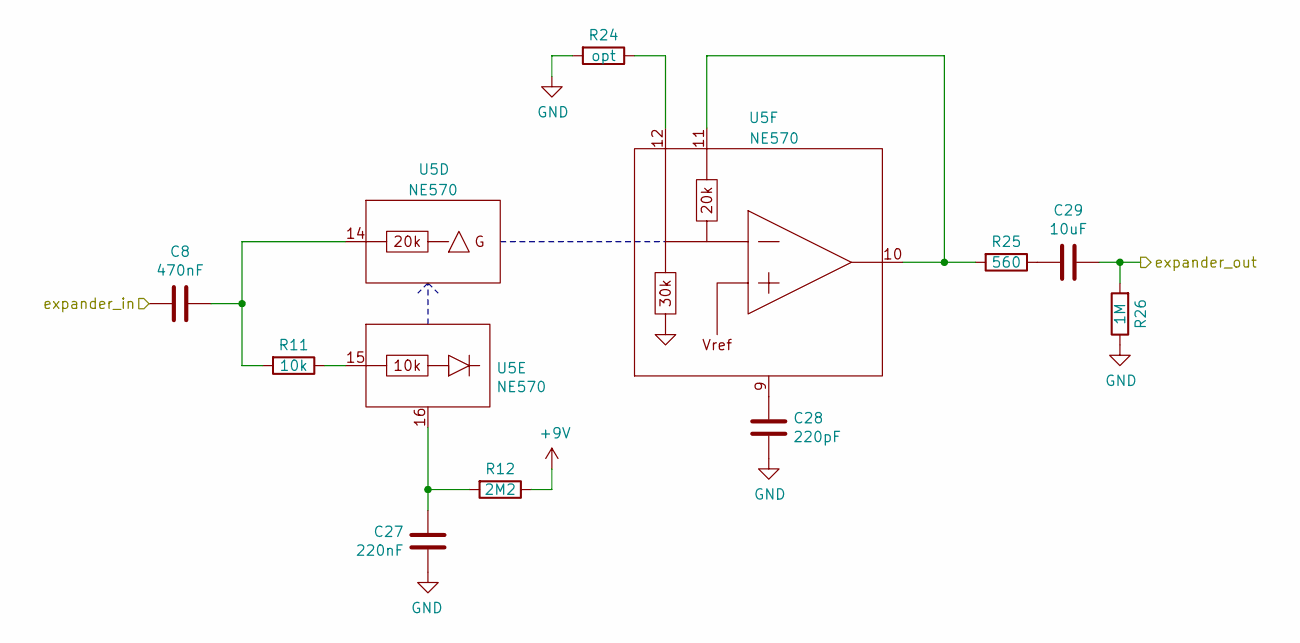
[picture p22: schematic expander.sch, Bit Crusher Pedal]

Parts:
C8: 470nF; C_0805_2012Metric_Pad1.15x1.40mm_HandSolder
C27: 220nF; C_0805_2012Metric_Pad1.15x1.40mm_HandSolder
C28: 220pF; C_0805_2012Metric_Pad1.15x1.40mm_HandSolder
C29: 10uF; C_0805_2012Metric_Pad1.15x1.40mm_HandSolder
R11: 10k; R_0805_2012Metric_Pad1.15x1.40mm_HandSolder
R12: 2M2; R_0805_2012Metric_Pad1.15x1.40mm_HandSolder
R24: opt; R_0805_2012Metric_Pad1.15x1.40mm_HandSolder
R25: 560; R_0805_2012Metric_Pad1.15x1.40mm_HandSolder
R26: 1M; R_0805_2012Metric_Pad1.15x1.40mm_HandSolder
U5: NE570; SOIC-16W_7.5x10.3mm_P1.27mm

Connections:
+9V: R12.1; also elsewhere on the board
/expander/expander_in: C8.2; also elsewhere on the board
/expander/expander_out: C29.1, R26.2; also elsewhere on the board
GND: C27.1, C28.2, R24.2, R26.1; also elsewhere on the board
unnamed: C8.1, R11.2, U5.14
unnamed: C27.2, R12.2, U5.16
unnamed: C28.1, U5.9
unnamed: C29.2, R25.1
unnamed: R11.1, U5.15
unnamed: R24.1, U5.12
unnamed: R25.2, U5.10, U5.11

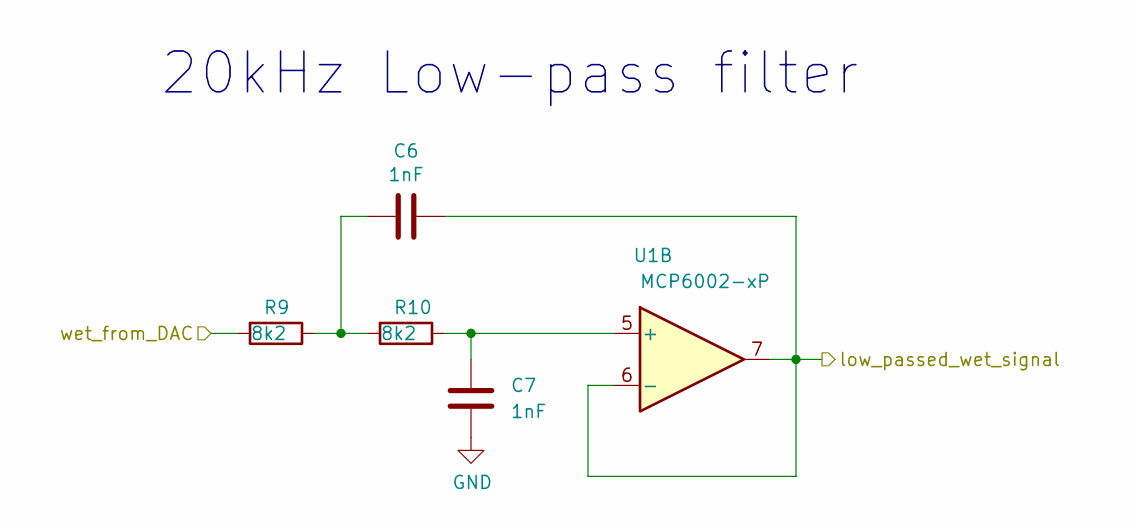
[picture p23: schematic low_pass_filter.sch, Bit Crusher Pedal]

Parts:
C6, C7: 1nF; C_0805_2012Metric_Pad1.15x1.40mm_HandSolder
R9, R10: 8k2; R_0805_2012Metric_Pad1.15x1.40mm_HandSolder
U1: MCP6002-xP; SOIC-8_3.9x4.9mm_P1.27mm

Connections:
/expander/expander_in: C6.1, U1.6 (-), U1.7; also elsewhere on the board
/microcontroller/DAC_out: R9.2; also elsewhere on the board
GND: C7.1; also elsewhere on the board
unnamed: C6.2, R9.1, R10.2
unnamed: C7.2, R10.1, U1.5 (+)

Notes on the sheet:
20kHz Low-pass filter

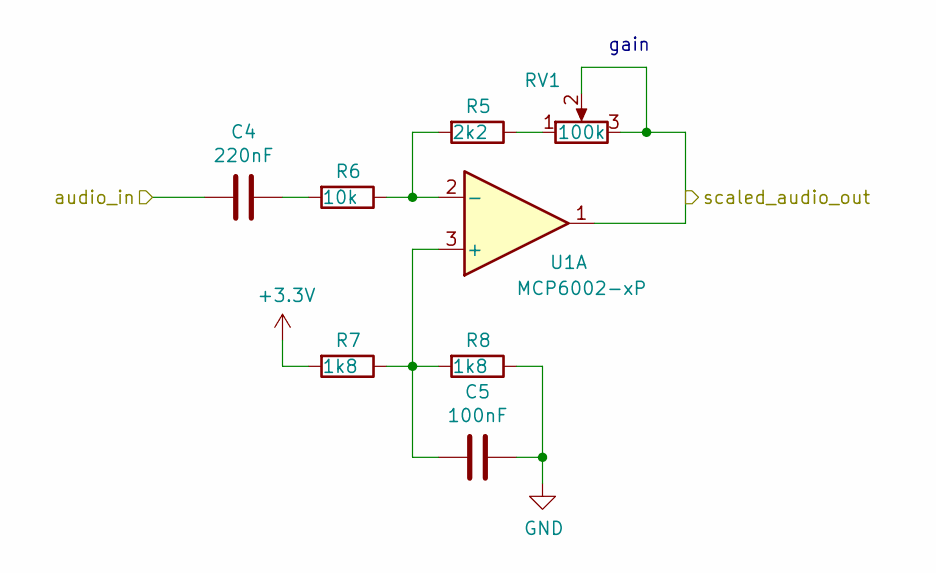
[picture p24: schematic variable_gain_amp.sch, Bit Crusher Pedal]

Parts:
C4: 220nF; C_0805_2012Metric_Pad1.15x1.40mm_HandSolder
C5: 100nF; C_0805_2012Metric_Pad1.15x1.40mm_HandSolder
R5: 2k2; R_0805_2012Metric_Pad1.15x1.40mm_HandSolder
R6: 10k; R_0805_2012Metric_Pad1.15x1.40mm_HandSolder
R7, R8: 1k8; R_0805_2012Metric_Pad1.15x1.40mm_HandSolder
RV1: 100k; Potentiometer_Alpha_RD901F-40-00D_Single_Vertical
U1: MCP6002-xP; SOIC-8_3.9x4.9mm_P1.27mm

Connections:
+3V3: R7.2; also elsewhere on the board
/microcontroller/ADC_in: RV1.2, RV1.3, U1.1; also elsewhere on the board
/variable_gain_amp/audio_in: C4.2; also elsewhere on the board
GND: C5.1, R8.1; also elsewhere on the board
unnamed: C4.1, R6.2
unnamed: C5.2, R7.1, R8.2, U1.3 (+)
unnamed: R5.1, RV1.1
unnamed: R5.2, R6.1, U1.2 (-)

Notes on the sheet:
gain

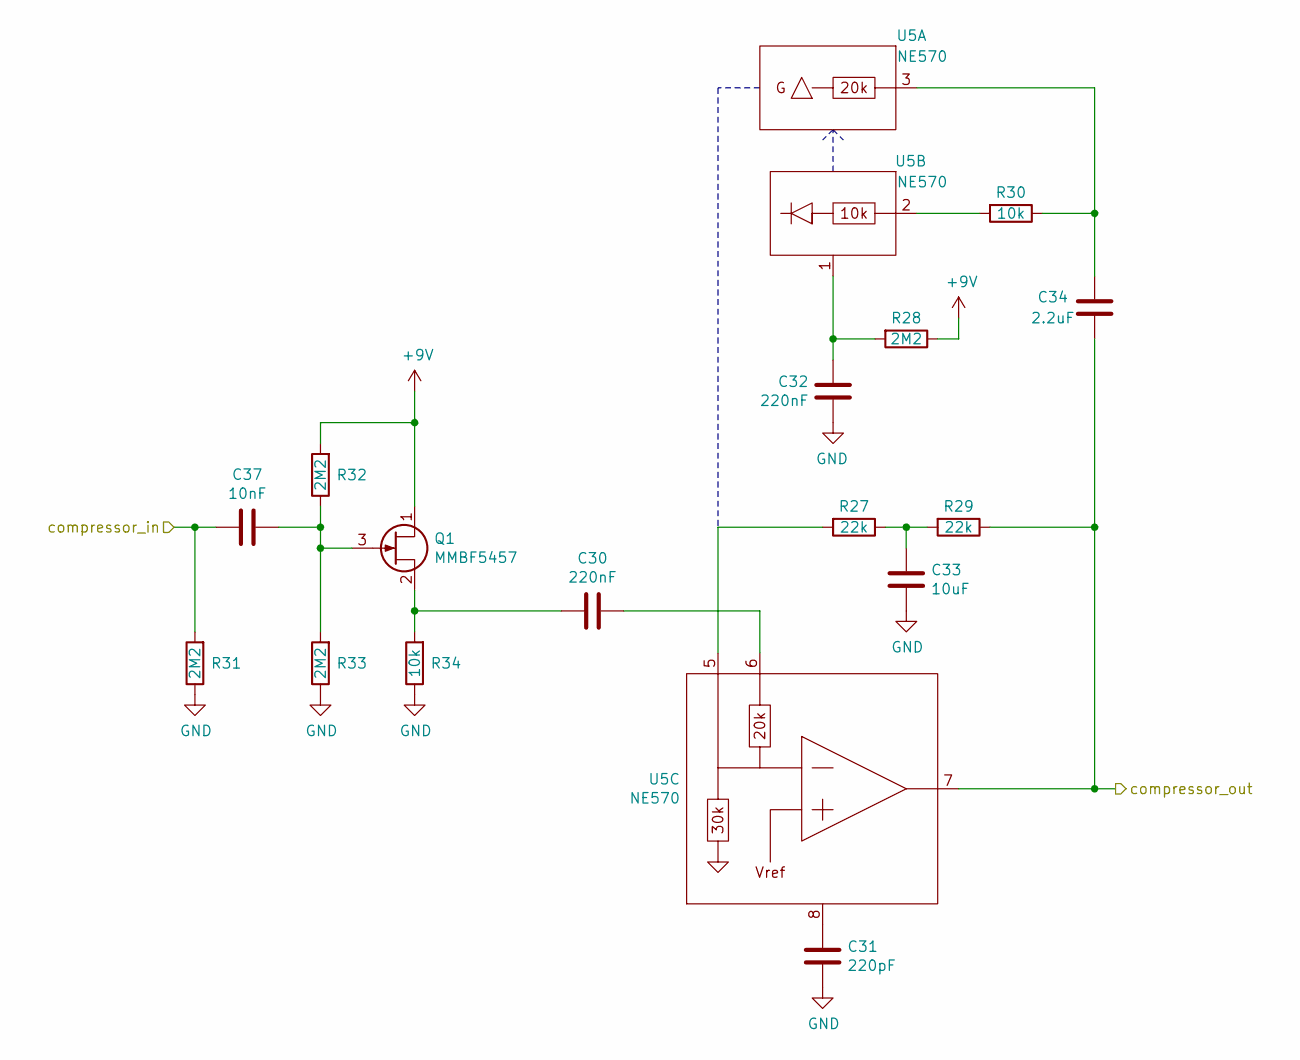
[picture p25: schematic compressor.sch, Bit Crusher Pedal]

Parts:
C30, C32: 220nF; C_0805_2012Metric_Pad1.15x1.40mm_HandSolder
C31: 220pF; C_0805_2012Metric_Pad1.15x1.40mm_HandSolder
C33: 10uF; C_0805_2012Metric_Pad1.15x1.40mm_HandSolder
C34: 2.2uF; C_0805_2012Metric_Pad1.15x1.40mm_HandSolder
C37: 10nF; C_0805_2012Metric_Pad1.15x1.40mm_HandSolder
Q1: MMBF5457; SOT-23_Handsoldering
R27, R29: 22k; R_0805_2012Metric_Pad1.15x1.40mm_HandSolder
R28, R31, R32, R33: 2M2; R_0805_2012Metric_Pad1.15x1.40mm_HandSolder
R30, R34: 10k; R_0805_2012Metric_Pad1.15x1.40mm_HandSolder
U5: NE570; SOIC-16W_7.5x10.3mm_P1.27mm

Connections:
+9V: Q1.1 (D), R28.1, R32.2; also elsewhere on the board
/compressor/compressor_in: C37.2, R31.2; also elsewhere on the board
/variable_gain_amp/audio_in: C34.2, R29.1, U5.7; also elsewhere on the board
GND: C31.1, C32.1, C33.1, R31.1, R33.1, R34.1; also elsewhere on the board
unnamed: C30.1, U5.6
unnamed: C30.2, Q1.2 (S), R34.2
unnamed: C31.2, U5.8
unnamed: C32.2, R28.2, U5.1
unnamed: C33.2, R27.1, R29.2
unnamed: C34.1, R30.1, U5.3
unnamed: C37.1, Q1.3 (G), R32.1, R33.2
unnamed: R27.2, U5.5
unnamed: R30.2, U5.2

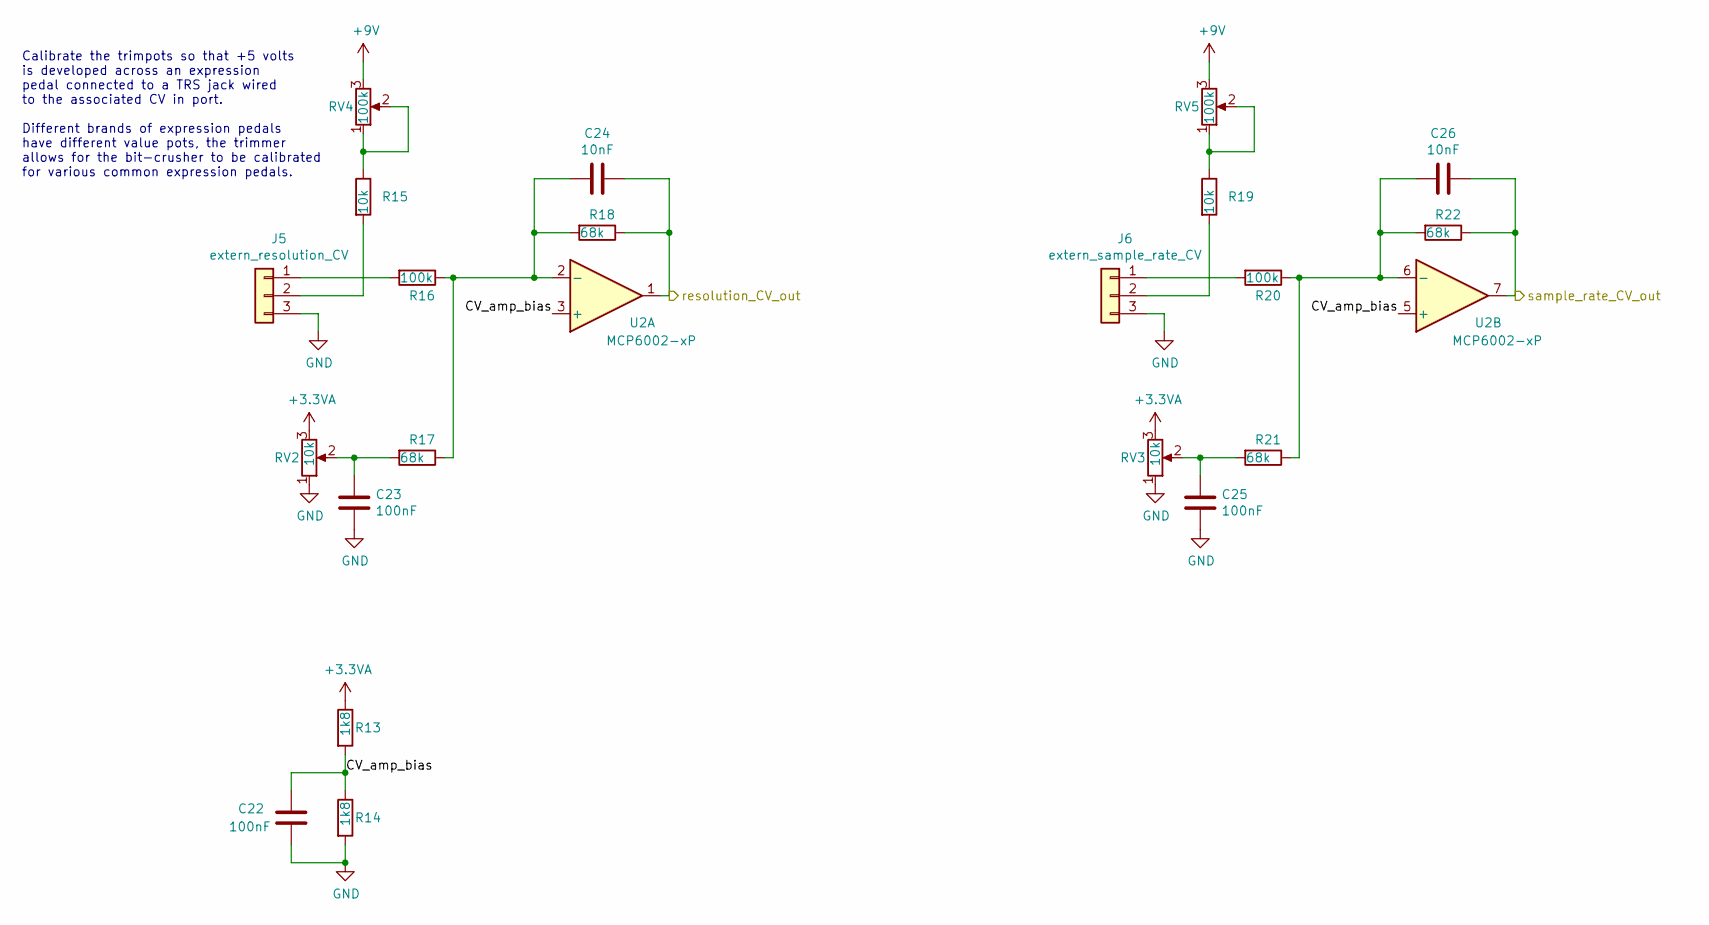
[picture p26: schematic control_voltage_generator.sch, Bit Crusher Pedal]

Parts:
C22, C23, C25: 100nF; C_0805_2012Metric_Pad1.15x1.40mm_HandSolder
C24, C26: 10nF; C_0805_2012Metric_Pad1.15x1.40mm_HandSolder
J5: extern_resolution_CV; PinHeader_1x03_P2.54mm_Vertical
J6: extern_sample_rate_CV; PinHeader_1x03_P2.54mm_Vertical
R13, R14: 1k8; R_0805_2012Metric_Pad1.15x1.40mm_HandSolder
R15, R19: 10k; R_0805_2012Metric_Pad1.15x1.40mm_HandSolder
R16, R20: 100k; R_0805_2012Metric_Pad1.15x1.40mm_HandSolder
R17, R18, R21, R22: 68k; R_0805_2012Metric_Pad1.15x1.40mm_HandSolder
RV2, RV3: 10k; Potentiometer_Alpha_RD901F-40-00D_Single_Vertical
RV4, RV5: 100k; Potentiometer_Bourns_3296W_Vertical
U2: MCP6002-xP; SOIC-8_3.9x4.9mm_P1.27mm

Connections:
+3.3VA: R13.1, RV2.3, RV3.3; also elsewhere on the board
+9V: RV4.3, RV5.3; also elsewhere on the board
/control_voltage_generator/CV_amp_bias: C22.1, R13.2, R14.1, U2.3 (+), U2.5 (+)
/microcontroller/resolution_CV_in: C24.1, R18.1, U2.1; also elsewhere on the board
/microcontroller/sample_rate_CV_in: C26.1, R22.1, U2.7; also elsewhere on the board
GND: C22.2, C23.2, C25.2, J5.3, J6.3, R14.2, RV2.1, RV3.1; also elsewhere on the board
unnamed: C23.1, R17.2, RV2.2
unnamed: C24.2, R16.1, R17.1, R18.2, U2.2 (-)
unnamed: C25.1, R21.2, RV3.2
unnamed: C26.2, R20.1, R21.1, R22.2, U2.6 (-)
unnamed: J5.1, R16.2
unnamed: J5.2, R15.2
unnamed: J6.1, R20.2
unnamed: J6.2, R19.2
unnamed: R15.1, RV4.1, RV4.2
unnamed: R19.1, RV5.1, RV5.2

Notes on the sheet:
Calibrate the trimpots so that +5 volts is developed across an expression pedal connected to a TRS jack wired to the associated CV in port. Different brands of expression pedals have different value pots, the trimmer allows for the bit-crusher to be calibrated for various common expression pedals.

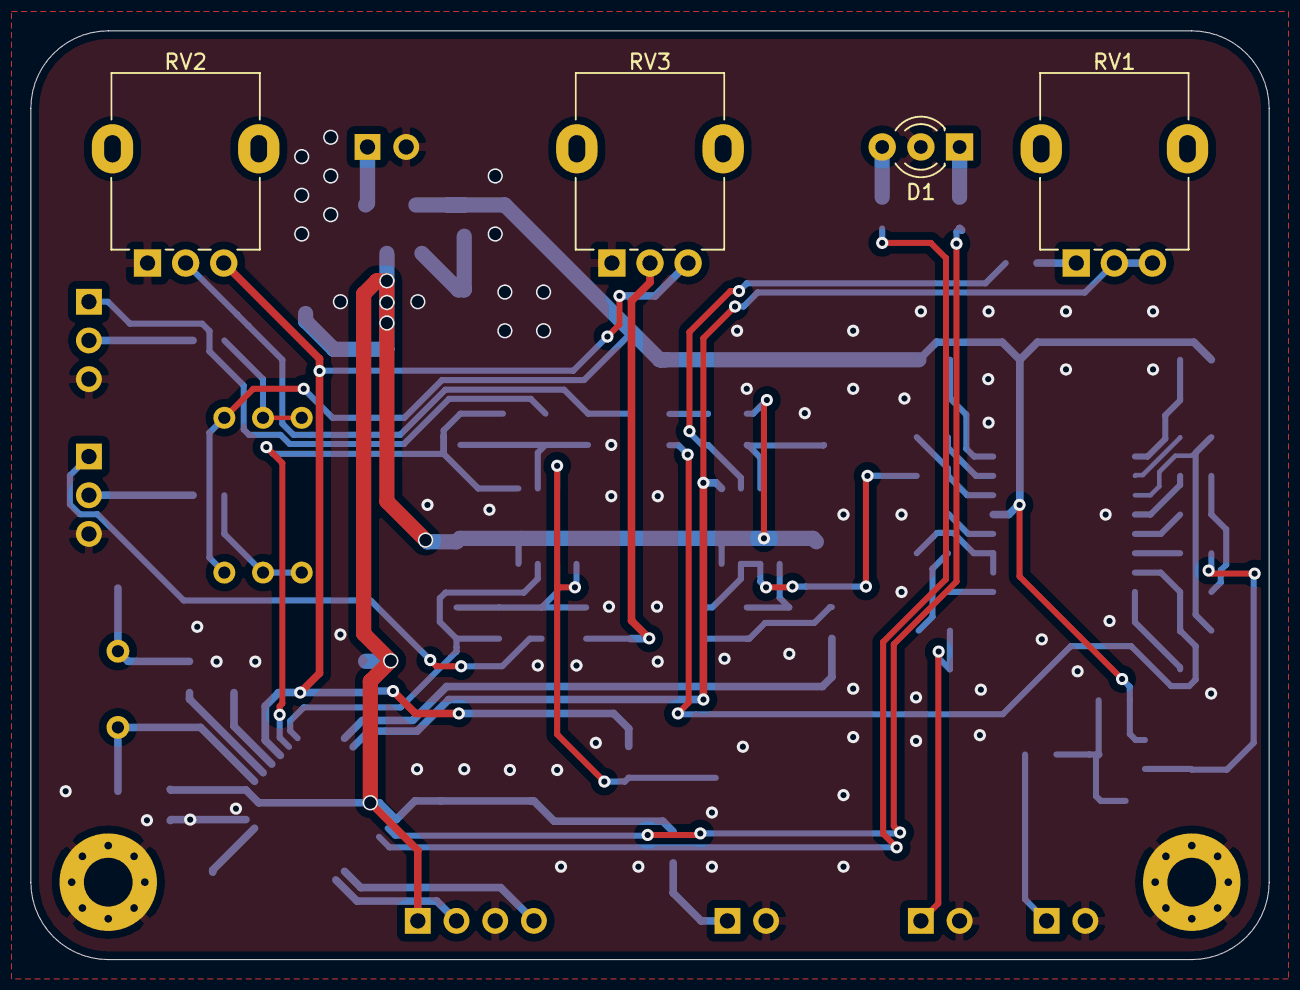
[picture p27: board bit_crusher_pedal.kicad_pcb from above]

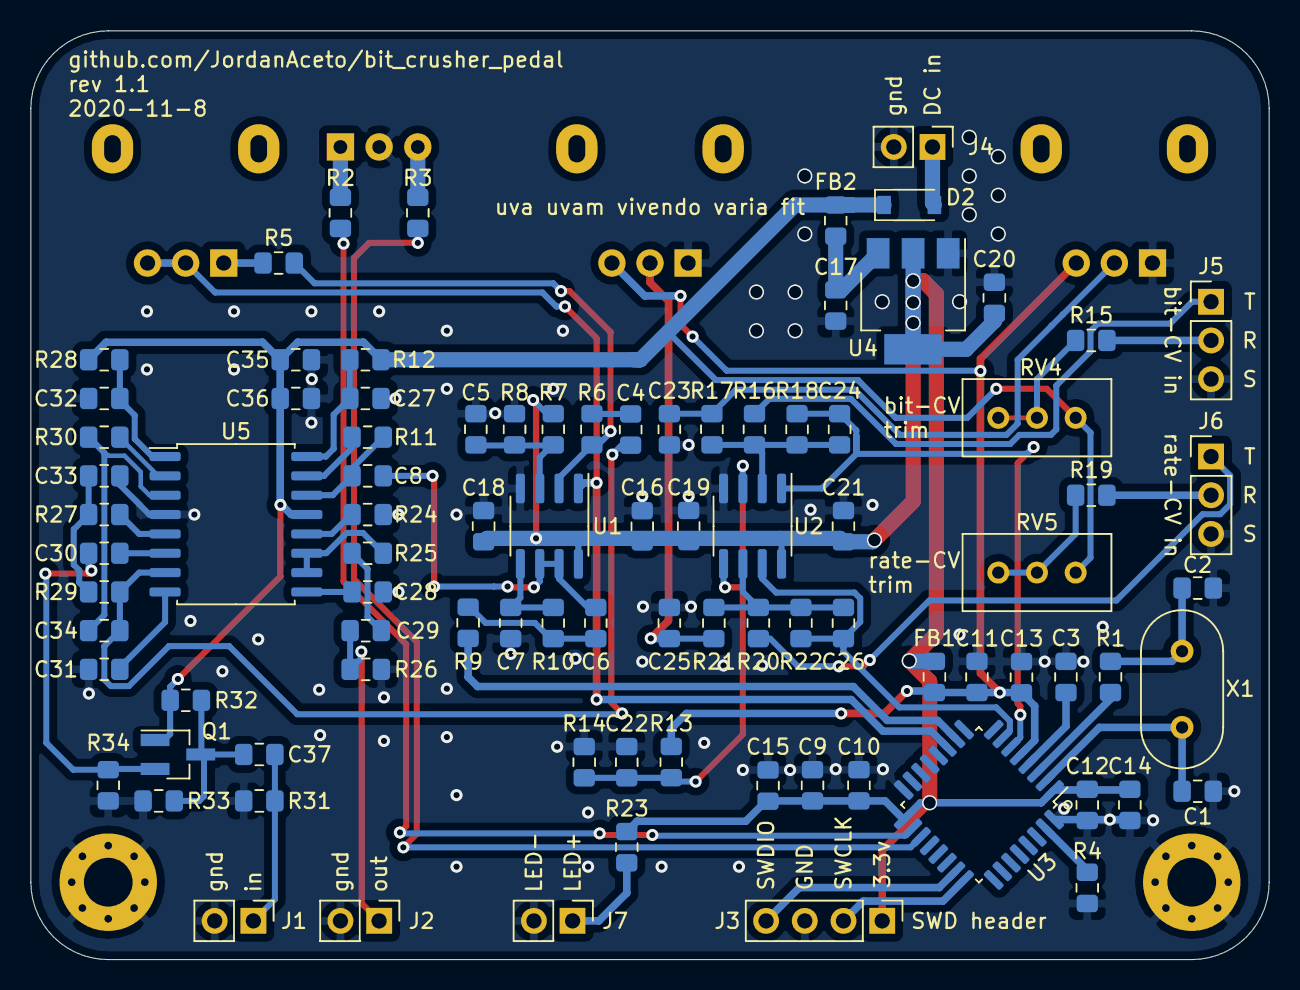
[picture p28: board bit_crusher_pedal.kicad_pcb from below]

Board: 2 copper layers, 81.3 x 61.0 mm, 96 parts (90 on the bottom side), 59 nets.

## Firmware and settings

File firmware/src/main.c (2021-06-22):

/*
--|----------------------------------------------------------------------------|
--| FILE DESCRIPTION:
--|   main.c provides the main application entry point implementation.
--|
--|----------------------------------------------------------------------------|
--| REFERENCES:
--|   None
--|
--|----------------------------------------------------------------------------|
*/

/*
--|----------------------------------------------------------------------------|
--| INCLUDE FILES
--|----------------------------------------------------------------------------|
*/

#include "bit_crusher.h"
#include "interrupts.h"
#include "LED_indicator.h"
#include "signal_IO.h"

/*
--|----------------------------------------------------------------------------|
--| PRIVATE FUNCTION PROTOTYPES
--|----------------------------------------------------------------------------|
*/

/*------------------------------------------------------------------------------
Function Name:
    main

Function Description:
    The main application.

Parameters:
    None

Returns:
    None

Assumptions/Limitations:
    Assumed that main will be called from the assembly startup routine after all
    system initialization is complete. Do not manually call this function.

    This function enters an infinite loop
    that is not expected to terminate.
------------------------------------------------------------------------------*/
int main(void);

/*
--|----------------------------------------------------------------------------|
--| PRIVATE FUNCTION DEFINITIONS
--|----------------------------------------------------------------------------|
*/

int main(void)
{
    while(1)
    {
        // read and scale the control signals and update the clipping LED periodically
        if (interrupt_get_flag(INTERRUPT_FLAG_TIM3))
        {
            set_audio_sample_rate(get_control_input_signal(CONTROL_INPUT_SAMPLE_RATE));

            LED_indicator_show_signal_strength(get_audio_input_signal());
        }

        // do the bit-crushing routine and update the output when the audio input signal is ready
        if (interrupt_get_flag(INTERRUPT_FLAG_TIM6))
        {
            write_audio_output_signal(
                crush(
                    get_audio_input_signal(),
                    get_control_input_signal(CONTROL_INPUT_BIT_DEPTH)
                )
            );
        }
    }

    // never reached
    return 0;
}

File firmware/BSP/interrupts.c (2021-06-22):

/*
--|----------------------------------------------------------------------------|
--| FILE DESCRIPTION:
--|   interrupts.h provides the implementation for the interrupts used by the 
--|   system.
--|   
--|  
--|----------------------------------------------------------------------------|
--| REFERENCES:
--|
--|----------------------------------------------------------------------------|
*/

/*
--|----------------------------------------------------------------------------|
--| INCLUDE FILES
--|----------------------------------------------------------------------------|
*/

#include "interrupts.h"
#include "stm32f3xx.h"

/*
--|----------------------------------------------------------------------------|
--| PRIVATE DEFINES
--|----------------------------------------------------------------------------|
*/

// note that for interrupts, higher numbers mean lower priority and vice versa

/*
--| NAME: TIM3_IRQ_PRIORITY
--| DESCRIPTION: the priority of the TIM3 interrupt, must be higher than TIM6
--| TYPE: uint
*/
#define TIM3_IRQ_PRIORITY (0u)

/*
--| NAME: TIM6_IRQ_PRIORITY
--| DESCRIPTION: the priority of the TIM6 interrupt
--| TYPE: uint
*/
#define TIM6_IRQ_PRIORITY (1u)

/*
--|----------------------------------------------------------------------------|
--| PRIVATE VARIABLES
--|----------------------------------------------------------------------------|
*/

/*
--| NAME: flags
--| DESCRIPTION: the interrupt flags used by the system
--| TYPE: bool
*/
static volatile bool flags[NUM_INTERRUPT_FLAG_TYPES];

/*
--|----------------------------------------------------------------------------|
--| PRIVATE HELPER FUNCTION PROTOTYPES
--|----------------------------------------------------------------------------|
*/

/*------------------------------------------------------------------------------
Function Name:
    interrupt_set_flag

Function Description:
    Set the specified interrupt flag.

Parameters:
    flag: the flag to set

Returns:
    None

Assumptions/Limitations:
    Assumed that the flag is a member of the Interrupt_Flag_t enumeration.
------------------------------------------------------------------------------*/
void interrupt_set_flag(Interrupt_Flag_t flag);

/*------------------------------------------------------------------------------
Function Name:
    interrupt_clear_flag

Function Description:
    Clear the specified interrupt flag.

Parameters:
    flag: the flag to clear

Returns:
    None

Assumptions/Limitations:
    Assumed that the flag is a member of the Interrupt_Flag_t enumeration.
------------------------------------------------------------------------------*/
void interrupt_clear_flag(Interrupt_Flag_t flag);

/*
--|----------------------------------------------------------------------------|
--| PUBLIC FUNCTION DEFINITIONS
--|----------------------------------------------------------------------------|
*/

void interrupts_Init(void)
{
    NVIC_SetPriority(TIM3_IRQn, TIM3_IRQ_PRIORITY);
    NVIC_EnableIRQ(TIM3_IRQn);

    NVIC_SetPriority(TIM6_DAC1_IRQn, TIM6_IRQ_PRIORITY);
    NVIC_EnableIRQ(TIM6_DAC1_IRQn);
}

bool interrupt_get_flag(Interrupt_Flag_t flag)
{
    const bool retval = flags[flag];
    interrupt_clear_flag(flag);
    return retval;
}

/*
--|----------------------------------------------------------------------------|
--| PRIVATE HELPER FUNCTION DEFINITIONS
--|----------------------------------------------------------------------------|
*/

void interrupt_set_flag(Interrupt_Flag_t flag)
{
    flags[flag] = true;
}

void interrupt_clear_flag(Interrupt_Flag_t flag)
{
    flags[flag] = false;
}

void TIM3_IRQHandler(void)
{
    interrupt_set_flag(INTERRUPT_FLAG_TIM3);

    // clear the Update Interrupt flag in the status register
    TIM3->SR &= ~TIM_SR_UIF;
}

void TIM6_DAC1_IRQHandler(void)
{
    interrupt_set_flag(INTERRUPT_FLAG_TIM6);

    // clear the Update Interrupt flag in the status register
    TIM6->SR &= ~TIM_SR_UIF;
}

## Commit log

2020-07-28 initial commit, main pcb started
    [audio_input.sch, audio_output.sch, bit_crusher_pedal.kicad_pcb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]
2020-07-29 start front panel
    [bit_crusher_front_panel.kicad_pcb]
2020-07-29 start jack panel
    [bit_crusher_jack_panel.kicad_pcb]
2020-07-29 generate BOM
2020-07-29 generate schematic
2020-07-29 generate gerbers
    [bit_crusher_front_panel.kicad_pcb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]
2020-07-29 generate jack panel gerbers
    [bit_crusher_jack_panel.kicad_pcb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]
2020-07-29 generate front panel gerbers
    [bit_crusher_front_panel-B_Cu.gbr, bit_crusher_front_panel-B_Mask.gbr, bit_crusher_front_panel-B_SilkS.gbr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]
2020-07-30 fix jack panel issue where front mask was missing
    [bit_crusher_jack_panel-B_Cu.gbr, bit_crusher_jack_panel-B_Mask.gbr, bit_crusher_jack_panel-B_SilkS.gbr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]
2020-08-17 add compander
    [bit_crusher_pedal-B_Cu.gbr, bit_crusher_pedal-B_Mask.gbr, bit_crusher_pedal-B_Paste.gbr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]
2020-08-17 add compander and FET datasheets
2020-08-17 reorganize directory structure
    [audio_input.sch, audio_output.sch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]
2020-08-18 add rev 1 main pcb docs
    [bit_crusher_pedal-B_Cu.gbr, bit_crusher_pedal-B_Mask.gbr, bit_crusher_pedal-B_Paste.gbr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]
2020-08-18 fix minor silkscreen issue
    [bit_crusher_pedal.kicad_pcb]
2020-08-18 switch trimpot rotation
    [bit_crusher_pedal-B_Cu.gbr, bit_crusher_pedal-B_Mask.gbr, bit_crusher_pedal-B_Paste.gbr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]
2020-08-20 change gain pot to 100k
    [bit_crusher_pedal.kicad_pcb, variable_gain_amp.sch]
2020-08-22 add some ADC code and test the ADC
2020-08-22 test the ADC
2020-08-24 get DMA working, tidy up
2020-08-24 tidy up interrupts
2020-08-24 add LED signal strength indicator
2020-08-24 tidy up LED signal indicator
2020-08-27 remove old DMA comment
2020-11-08 rev 1.1, fix silkscreen, flip trimpots, adjust hpf
    [bit_crusher_pedal-B_Cu.gbr, bit_crusher_pedal-B_Mask.gbr, bit_crusher_pedal-B_Paste.gbr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]
2020-11-08 flip trimpots again, hopefully right this time
    [bit_crusher_pedal-B_Cu.gbr, bit_crusher_pedal-B_Mask.gbr, bit_crusher_pedal-B_SilkS.gbr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]
2020-11-09 rearrange schematic pages
2020-11-09 fix page order in schematic pdf
2020-11-11 update main pcb readme
2020-11-16 add offboard wiring diagram
    [bit_crusher_offboard_wiring.sch]
2021-06-10 add DC jack and enclosure datasheets
2021-06-11 add drill guides
    [front_drill_guide.kicad_pcb, jacks_drill_guide.kicad_pcb]
2021-06-11 add drill guide readme
2021-06-22 reorder schematic pages
    [bit_crusher_pedal.sch]

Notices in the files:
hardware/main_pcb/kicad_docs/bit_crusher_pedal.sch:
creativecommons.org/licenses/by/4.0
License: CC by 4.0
